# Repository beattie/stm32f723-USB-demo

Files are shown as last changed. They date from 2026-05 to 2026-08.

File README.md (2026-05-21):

# STM32F723 USB Passthrough Demo

A hardware and firmware demonstration platform based on the STM32F723VET6, a Cortex-M7
with an embedded USB HS PHY. Inspired by the [Pastilda](https://github.com/nickcoutsos/pastilda)
project, with a goal of providing robust Linux support for USB keyboard passthrough. This project was started as a vehicle to learn Rust and keep my USB up-to date as well as display my limited HW design abilities.

## Concept

The board sits between a USB keyboard and a Linux host. The firmware intercepts keystrokes,
allowing for key remapping, macros, and other HID transformations entirely in hardware —
no kernel modules or userspace daemons required on the host.

## Hardware

Designed in KiCad. The STM32F723 was chosen for its embedded USB HS PHY, which allows
full-speed USB HS without an external PHY chip.

**Key interfaces:**
- USB-C device port to host (USB 2.0 HS)
- USB-A host port for keyboard (USB FS)
- USB-C power input
- MicroSD — for config and macro storage
- SPI LCD connector — optional display
- SWD debug header

**Hardware versions:**
- Rev 0.1 — 2-layer board, initial bring-up (bring-up in progress)
- Rev 0.2 — 4-layer board (F.Cu / GND / 3V3 / B.Cu), revised layout (design in progress)

PCB gerbers for Rev 0.1 are in `kicad/gerbers/`.

## Firmware

Written in Rust using the [Embassy](https://embassy.dev/) async embedded framework.

```
src/main.rs      — application entry point
Cargo.toml       — dependencies
memory.x         — linker memory map for STM32F723VE
```

**Build:**
```bash
cargo build --release
```

Requires the `thumbv7em-none-eabihf` target:
```bash
rustup target add thumbv7em-none-eabihf
```

**Flash:**
```bash
cargo flash --release --chip STM32F723VETx
```
Or use OpenOCD/probe-rs via the SWD header.

## Bill of Materials

See [BOM.md](BOM.md) for the full parts list with Digikey part numbers.

## License

Hardware and firmware are released under CERN-OHL-S v2 / GPL v3 respectively.

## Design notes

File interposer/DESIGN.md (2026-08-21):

# Interposer Secure Storage Device — Design Draft

## Overview

A USB interposer device that sits between a keyboard and a host computer. It presents as a composite USB device: a HID keyboard (passthrough) and a mass storage device (SD card). The device provides two security services:

1. **Password manager** — stores credentials encrypted on SD; types them via HID on user request
2. **Secure file store** — stores encrypted files on SD; decrypts and transfers content to host via HID typing or a temporary plaintext staging file

The host requires no special software. All security operations are performed on the device using the passthrough keyboard for input and the ST7735 display for UI.

---

## Threat Model

**Protected against:**
- Theft of SD card alone — all sensitive content is encrypted
- Theft of device alone — requires user passphrase to derive key
- Brute force of passphrase — KDF is intentionally slow; device secret adds a second factor

**Not protected against:**
- Physical possession of device AND knowledge of passphrase
- Host keyloggers (HID typing path exposes plaintext to a compromised host)
- Destruction or corruption of SD card contents

**Out of scope:**
- Protection against a sophisticated attacker with lab equipment and the physical device
- Forward secrecy
- Multi-user access

---

## Hardware

- **SoC**: STM32F723VET6, Cortex-M7, 216MHz
- **Storage**: Full-size SD card via SDMMC1 (1-bit mode, 4-bit pending)
- **Display**: ST7735 1.44" 128×128 SPI
- **USB device**: OTG_HS (USB-C), composite HID keyboard + MSC
- **USB host**: OTG_FS (USB-A), HID keyboard input
- **TRNG**: STM32 hardware RNG — used for salt/nonce/key generation
- **Unique ID**: STM32 96-bit factory UID at 0x1FF0F420 — part of device secret

---

## Key Derivation

```
device_secret = flash_secret || uid_96bit
encryption_key = Argon2id(
    passphrase  = user_passphrase,
    salt        = device_secret,
    m = 65536,          // 64MB memory — adjust for RAM constraints
    t = 3,              // iterations
    p = 1               // parallelism
)
```

**flash_secret**: 32 bytes of TRNG-generated random data, written to a dedicated flash sector during first-boot provisioning. Never exposed over any interface. Protected by STM32 RDP Level 1 when device is sealed.

**uid_96bit**: Factory-programmed, read-only. Ensures encryption_key is device-specific even if flash_secret is somehow compromised.

**Note**: STM32F723 has 256KB RAM. Argon2id memory parameter must fit — 64MB does not. Realistic target is 128–256KB. This weakens brute-force resistance; compensate with a stronger passphrase.

---

## Flash Layout

```
Sector 0–N-1   Firmware
Sector N        Device secret (32 bytes TRNG, written once at provisioning)
                [ remainder of sector unused ]
```

Sector N chosen to avoid firmware overlap. At RDP Level 1, entire flash is unreadable externally. At RDP Level 2, device is permanently sealed.

---

## SD Card Layout

Ordinary FAT32 filesystem, mountable on any host. Sensitive files use the `.sec` extension — opaque encrypted blobs to any host without the key.

```
/
├── password.sec       — encrypted password database
├── README.txt         — plaintext, explains the device to a curious host user
└── files/
    └── *.sec          — user encrypted files
```

The host can freely copy, move, or delete `.sec` files. The device manages their contents.

---

## Encrypted Object Format

```
Offset  Size  Field
0       4     Magic: "ISEC"
4       1     Version: 0x01
5       1     Type: 0x01=password_db, 0x02=text_file, 0x03=binary_file
6       2     Reserved
8       12    Nonce (TRNG-generated per encryption)
20      4     Plaintext length
24      N     ChaCha20-Poly1305 ciphertext + 16-byte tag
```

**Cipher**: ChaCha20-Poly1305 (AEAD) — software implementation via RustCrypto, no hardware CRYP needed. Provides confidentiality + integrity; a tampered file will fail authentication.

---

## Password Database Format (plaintext, before encryption)

INI-style, section-per-entry. Human-readable and editable with any text editor before encryption.

```ini
IPMGR

[github.com]
username = beattie
password = Kx7!mP2#qL
comment = work account

[gmail.com]
username = beattie@gmail.com
password = correct-horse-battery
```

**Rules:**
- First line is the magic header `IPMGR`
- Each entry is a `[section]` where the section name is the site label shown on the display
- Fields are `key = value` — order within a section does not matter
- Blank lines between entries are ignored
- Unknown fields are preserved on re-write (forward compatibility)
- `comment` field is optional — shown on display, not typed to host

**Known fields:** `username`, `password`, `comment`

**Open question:** encrypt the whole file as one blob, or encrypt only the password fields and keep structure plaintext. Whole-file is simpler and leaks no metadata; per-field allows browsing entry names without the key. Decision deferred.

After encryption stored as `password.sec`.

---

## Device Modes / State Machine

```
LOCKED
  │  user types passphrase on keyboard
  ▼
UNLOCKED
  ├── PASSTHROUGH   — keystrokes forwarded to host normally
  ├── PM_SELECT     — display shows credential list; Up/Down selects
  ├── PM_TYPE_USER  — device types username via HID
  ├── PM_WAIT       — waiting for user to press Enter/Tab to type password
  └── FILE_SELECT   — display shows file list; select to decrypt+transfer
```

**Trigger**: a key combination (e.g. Scroll Lock, or a configurable combo) switches from PASSTHROUGH to PM_SELECT while unlocked.

**Lock**: device re-locks after configurable idle timeout, or on explicit lock key combo. Derived key is zeroed from RAM.

---

## Transfer Mechanisms

**Password typing (PM path):**
1. Device decrypts `password.sec` in RAM
2. User selects entry on display
3. On Enter: device types username via HID
4. On next Enter: device types password via HID
5. Plaintext held in RAM only; zeroed after use

**Secure file transfer:**
1. User selects `.sec` file on display
2. Device decrypts to RAM (size limited by available RAM — ~200KB usable)
3. Device creates `PLAIN.TXT` on FAT, writes plaintext
4. Host reads file normally (no special software)
5. After timeout (e.g. 60s) or explicit lock: device overwrites `PLAIN.TXT` with zeros, deletes it
6. Display shows countdown

**Encrypt a host-written file:**
1. Host writes plaintext file to FAT (e.g. `newfile.txt`)
2. User selects it on device display, confirms
3. Device reads plaintext, encrypts, writes `newfile.sec`, deletes `newfile.txt`

---

## Password Entry & Generation

### Manual entry

New credentials entered on-device using the passthrough keyboard:

1. User triggers "new entry" mode from PM_SELECT
2. Display shows `Site:` — user types site/username, presses Enter
3. Display shows `Password:` — user types password, OR presses a key to generate
4. Device appends entry to `password.sec` (decrypt → append → re-encrypt)

### Random generation

- **Source**: STM32 hardware TRNG — already present, used for nonces
- **Character set**: `a-z A-Z 0-9 !@#$%^&*-_+=` (no ambiguous chars like `0O1lI`)
- **Default length**: 20 characters; configurable 12–32
- **UX**: generated password shown on display before committing — user can confirm or regenerate
- **On confirm**: entry stored in `password.sec` AND typed to host via HID so the site receives it immediately

Word-based (diceware) passwords not implemented: wordlist (~80KB) would need to live on SD card, adds complexity, and many sites reject passphrases.

### Implementation dependency

Both manual entry and random generation require a **text input loop**: reading keystrokes from the passthrough keyboard (already captured in `kbd_task`) and echoing masked input on the display. This is the foundation all password manager UI builds on.

---

## Future Features

### FIDO2 / WebAuthn

A FIDO2 token eliminates the need to type passwords entirely for supported sites. The site sends a challenge, the device signs it with a per-site private key, the site verifies. The secret never leaves the device — immune to host keyloggers and phishing, stronger than HID typing for authentication.

**What's needed:**
- CTAP2 protocol over USB HID (usage page 0xF1D0) — a separate HID interface alongside the keyboard HID; embassy-usb supports multiple HID interfaces
- Per-site EC key pairs (P-256 or Ed25519), generated on device, stored encrypted on SD
- User presence confirmation — button press or PIN; display can show which site is requesting
- Resident keys (discoverable credentials) for passwordless login
- Spec: FIDO Alliance CTAP2 (open); reference implementation: SoloKeys (open source)

**Fit with this hardware:**
- Display is a genuine advantage over most FIDO2 tokens — can show the relying party ID before confirming
- RustCrypto has P-256 (`p256`) and Ed25519 (`ed25519-dalek`)
- Flash estimate: ~80KB additional

**Priority:** High — clean security model, open spec, good open source reference, doesn't require host software once registered.

---

### Monero Support

Monero's view key / spend key separation is well-suited to a hardware wallet: share the view key with a watch-only wallet to monitor incoming transactions, keep the spend key on the device.

**Realistic subset (feasible on this hardware):**
- Seed storage (Monero 25-word or BIP39 format) — encrypted on SD, same key derivation as secure storage
- View key export — derive and display/type the view key for import into Feather Wallet or Monero CLI
- Ed25519-Monero signing for simple transactions
- Host interface: Trezor protocol (Feather Wallet already supports it) or custom

**What's probably out of reach:**
- Full RingCT / Bulletproofs proving — computationally and memory intensive; Bulletproofs require significant RAM for the proof construction
- Full privacy-preserving transaction signing on-device

**What's needed:**
- Ed25519-Monero curve arithmetic (a variant of standard Ed25519) — RustCrypto `curve25519-dalek` is a starting point
- Monero key derivation (Keccak-256, not SHA-3) — RustCrypto `tiny-keccak`
- Companion software on host required (Feather Wallet or Monero CLI with hardware wallet support)
- Reference: Trezor Monero implementation (open source)

**Flash estimate:** ~100KB for Ed25519-Monero + key derivation + Trezor protocol subset.

**Priority:** Medium — personally useful (eris Monero node), simpler subset is feasible, full RingCT is not.

---

### Code Space Reality Check (STM32F723: 512KB flash, 256KB RAM)

| Component | Flash estimate |
|---|---|
| Current firmware (USB host+device, MSC, display, SD) | ~150KB |
| Secure storage (ChaCha20-Poly1305, Argon2id, FAT) | ~100KB |
| FIDO2 (CTAP2, P-256/Ed25519, key storage) | ~80KB |
| Monero subset (Ed25519-Monero, seed, view key) | ~100KB |
| **All four** | **~430KB** — tight but possibly feasible |

RAM is the harder constraint. Argon2id memory parameter and crypto buffers compete with USB stack and task stacks. Measure actual usage after core secure storage is implemented before committing to FIDO2 + Monero simultaneously.

---

## Open Questions

1. **Argon2id memory parameter** — 256KB RAM leaves very little headroom after firmware stack/data. May need PBKDF2 instead, with a stronger passphrase requirement.
2. **Key caching** — re-derive key on each operation, or cache in RAM for the session? Caching is faster but key lives in RAM longer.
3. **Passphrase entry UX** — display shows character count only (no echo), or masked echo (dots)? Confirmation by retyping?
4. **File size limit** — decrypt-to-RAM limits secure files to ~150–200KB. Larger files need streaming decrypt, which is more complex.
5. **Staging file timing** — fixed timeout for `PLAIN.TXT` exposure, or user-initiated wipe?
6. **Provisioning UX** — first boot generates and writes flash_secret automatically, or requires an explicit provisioning step?
7. **RDP sealing** — manual step, or triggered from device UI?

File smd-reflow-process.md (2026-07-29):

# SMD Reflow Process — Electric Skillet

## Equipment and Materials

- Electric skillet (dedicated, not for food)
- IR thermometer with adjustable emissivity (Surpeer GM550)
- Laser-cut stencil (0.12mm for mixed 0603 / LQFP100 0.5mm pitch)
- Solder paste: Chip Quik TS391AX50 Sn63Pb37 no-clean
- Scrap PCB (temperature reference target — see Skillet Setup)
- Squeegee or old credit card
- Tweezers (fine tip) or vacuum pen for component placement
- Isopropyl alcohol 90%+ and toothbrush for cleaning
- Silicone soldering mat (table protection)
- Magnification (loupe or microscope) for inspection
- Solder wick and flux for rework

---

## Paste Storage

- Store paste refrigerated when not in use
- Before use: remove from fridge, leave **closed** at room temperature for 30–60 minutes
- Opening a cold jar causes condensation which contaminates the paste
- Once opened, paste has a working life of several hours; do not leave uncovered
- Return unused paste to the fridge

NB: Chip Quick TS391AX50 is listed as Thermally Stable, may not need redrigeration.

---

## Skillet Setup

1. Place silicone mat on work surface, skillet on top
2. **Do not use aluminum foil** — foil acts as a heat sink and limits peak temperature to ~190°C, which is below the reflow zone for Sn63Pb37. Without foil, the skillet surface cycles correctly between 200–220°C.
3. Place a scrap PCB in the skillet as your IR temperature reference target. Set IR thermometer emissivity to ε=0.95 and read the bare PCB surface — permanent marker on PCB reads essentially the same as bare PCB, either works. Keep the reference PCB close to where your board will sit.

**What does not work for IR reference:**
- Bare skillet surface: reads 30–50°C cold (reflective metal)
- Black electrical tape on skillet: also reads cold, and puckers/deforms above 150°C (PVC melts)
- Black tape or marker must be on a PCB substrate to give accurate readings

---

## Skillet Calibration (First Use)

Map your dial to actual temperature before reflowing a real board:

1. Place scrap PCB reference in skillet; set IR thermometer to ε=0.95
2. Turn skillet to maximum (no foil)
3. Measure PCB temperature at intervals and note the time

**Observed ramp (this skillet, cold start ~28–33°C, maximum dial, no foil):**

| Time | PCB Temperature | Event |
|---|---|---|
| 0:00 | 28–33°C | Start |
| 4:00 | ~150°C | |
| 6:12 | 183°C | Liquidus (up) |
| 6:21 | ~191°C | Paste goes shiny |
| 7:00 | ~200°C | |
| 8:30 | ~220°C | |

Ramp rate is ~0.4°C/s — slow enough that the paste preheat/soak profile is satisfied naturally on the way up. No need to hold at an intermediate temperature. **Liquidus onset is consistent at ~6:21 across multiple runs.**

**Time above liquidus (TAL) by kill-heat strategy:**

| Strategy | Kill heat | TAL | Peak | Suitable for components? |
|---|---|-----|---|---|
| 220°C dial mark / neon out | ~8:01 | ~5 min | 222°C | No — 6× over spec |
| Max dial / neon out | ~10:17 | ~9 min | 249°C | No — way over spec |
| **Liquidus + 30–60s** | **~6:50–7:20** | **~90–108s** | **~200–205°C** | **Yes ✓** |

**Use the liquidus + 30–60s strategy for all populated boards.** The neon-out strategies give excessive TAL and excessive peak temperatures regardless of dial setting — the neon is useful only as a calibration reference, not as the reflow trigger.

**Cooldown:** Move board to silicone mat once reference PCB reads 150°C (solder solidified well above this — tap a large pad gently to confirm if unsure).

Skillet dials are inaccurate — calibrate before first use and mark the dial.

---

## Stencil and Paste Application

### Alignment
1. Secure the bare PCB flat on your work surface — tape the corners or use a frame to prevent movement
2. Lay the stencil over the board, aligning apertures to pads
3. Hold or tape the stencil edges so it cannot shift during squeegee pass
4. The stencil must lie flat with no gap between stencil and board surface — paste will bleed under a lifted stencil

### Paste Application
1. Apply a bead of paste along one edge of the stencil (slightly more than you think you need)
2. Hold squeegee or credit card at **45°** angle
3. Draw across the stencil in **one firm, smooth pass** — don't go back and forth
4. Consistent pressure and angle give consistent paste volume
5. Carefully lift the stencil **straight up** — peeling at an angle smears the deposits

### Inspection Before Placing Parts
- Check every pad under magnification before placing components
- Look for: missed pads, bridges between adjacent pads, uneven deposit volume
- Fine-pitch pads (LQFP100) are most likely to bridge — inspect carefully
- Fix problems now with a toothpick; much harder after components are placed

---

## Component Placement

- Work from smallest/lowest components to largest/tallest
- Tweezers: fine tip, grip component by the body not the leads
- Vacuum pen: faster for larger components, less control on small ones
- Place components into the paste — they should sit level and centered on the pads
- Paste is tacky enough to hold parts in place; don't press hard or you'll displace paste
- Double-check orientation on polarized components (caps, diodes, ICs) before reflow — much easier to fix now

---

## Reflow

### Temperature Profile (Sn63Pb37)
| Phase | Temperature | Notes |
|---|---|---|
| Preheat | ramp to ~150°C | Activates flux, evaporates solvents |
| Soak | hold ~150°C briefly | Equalizes board temperature |
| Reflow | push to 205–215°C | Watch for paste transition |
| Cool | kill heat, leave on skillet | Let solder solidify before moving |

### Process
1. Place scrap PCB reference target in skillet next to where the board will sit
2. Place populated board on **cold** skillet
3. Turn dial to **maximum**
4. Wait — expect approximately **8–9 minutes** before reflow at this ramp rate. The slow ramp naturally covers the preheat and soak phases on the way up; no intermediate dial step needed.
5. Watch the paste: it will go dull/gray → slightly transparent (flux working) → **bright shiny silver** (reflow). The visual transition is the primary trigger — timing is only a rough guide. **Tip:** apply a small dab of paste to a visible test point or exposed pad — gives an unobstructed view of the reflow transition since paste under IC pins can't be seen directly.
6. Once reflow is visible, start a timer and hold for **30–60 seconds**
7. **Kill the heat** — turn dial to off. Do not wait for the neon pilot light to go out; that gives ~5–9 minutes TAL depending on dial setting, which is too long for components.
8. Leave board on skillet. Move to silicone mat once reference PCB reads **150°C** — solder is solid well before this point. Tap a large pad gently to confirm solidity if uncertain.

---

## Post-Reflow Inspection

Under magnification, check for:

- **Good joint**: shiny, smooth fillet, wets both pad and component lead
- **Bridge**: solder connecting two adjacent pads — most common on fine-pitch
- **Tombstone**: component standing on one end, one pad reflowed before the other — caused by uneven paste or component not centered
- **Cold joint**: dull, grainy surface — insufficient temperature or movement during solidification
- **Insufficient solder**: pad wetted but joint looks thin — check paste volume on stencil setup

---

## Rework

### Bridges
1. Apply liquid flux to the bridge
2. Touch solder wick to the bridge with a hot iron — wick pulls excess solder away
3. Clean flux residue with IPA

### Tombstoned Component
1. Apply flux
2. Reflow both pads with hot air or iron, press component flat while liquid
3. Alternatively: remove component, clean pads, re-paste, replace

### Cold Joint
1. Apply flux
2. Reflow with iron or hot air — good flux and heat usually fixes it

### Hand Application (Single Pads / Rework Only)
- Use a toothpick or syringe to apply a small amount of paste to individual pads
- Or use flux + solder wire with an iron for single joints
- Not recommended for whole-board paste application

---

## Cleaning

Chip Quik TS391AX50 is no-clean — residue is non-corrosive and can be left on the board. Cleaning is still recommended:

1. Apply IPA (90%+) to board
2. Scrub with toothbrush, working around components
3. Rinse with fresh IPA
4. Allow to dry completely before powering up

---

## Ventilation

Flux fumes during reflow are unpleasant and mildly irritating. Work near an open window or with a fan exhausting away from you. A small fume extractor is worthwhile if you do this regularly.

---

## Notes

- **Do not mix bismuth and tin-lead solder** — the alloys blend and the melting point drops unpredictably
- Bismuth paste (lower temp ~138°C) is useful for learning skillet technique but produces more brittle joints
- Tin-lead (Sn63/Pb37) is preferred for production boards — sharper melt at 183°C, more forgiving
- Stencil thickness: **0.12mm** for mixed 0603 / LQFP100 0.5mm pitch

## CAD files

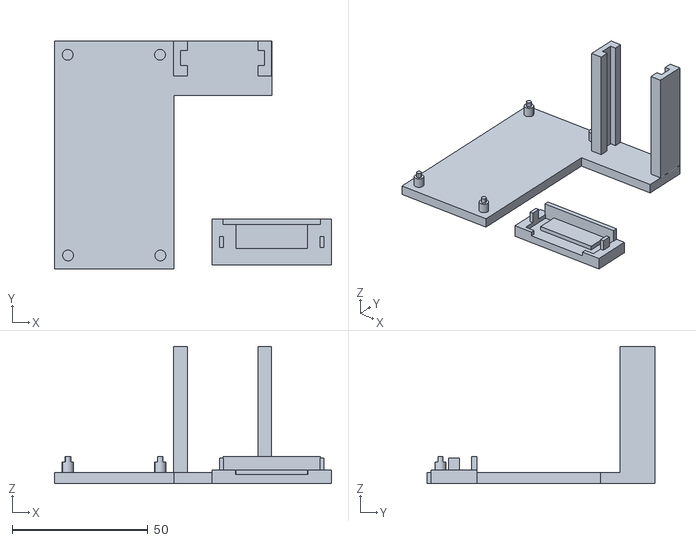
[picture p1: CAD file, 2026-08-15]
3dprint/baseplate_display.stl
102.0 x 84.0 x 50.5

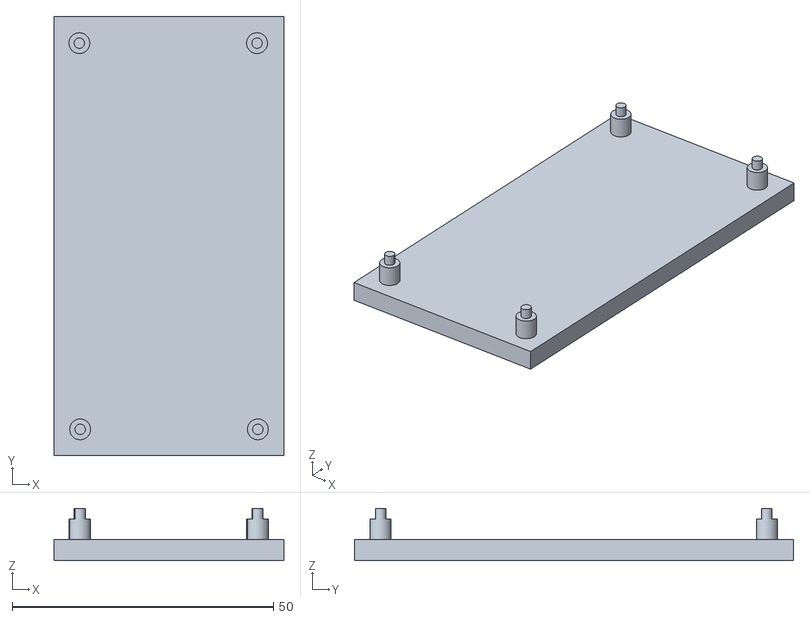
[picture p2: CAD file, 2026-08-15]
3dprint/baseplate.stl
44.0 x 84.0 x 10.0

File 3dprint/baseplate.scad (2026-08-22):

// STM32F723 USB Interposer board base plate
// This is a Q&D hack to solve two problems,
// since there is a connector on the bottom
// the board tends to rock when probeing, the
// display just tends to flop around and not
// be visable. This fixes both, it is not
// well fitted or elegant.
//
// Board: 40x80mm, 4x M2.2 mounting holes
// Standoffs: 4mm dia, 4mm tall; pins: 2mm dia,
// 2mm tall (for 2mm screws / press fit)

board_w      = 40;
board_h      = 80;
margin       = 2;       // extra plate beyond board edge on each side
plate_thick  = 4;
standoff_d   = 4;
standoff_h   = 4;
pin_d        = 2;       // fits 2.2mm hole with 0.1mm clearance each side
pin_h        = 2;

display_w    = 30;
display_h    = 43.5;
display_t    = 5;
extension_w  = 36;
extension_l  = 20;

plate_w = board_w + 2*margin;
plate_l = board_h + 2*margin;

// Hole positions relative to board top-left corner (mm), from KiCad PCB
holes = [
    [ 3.00,  3.00 ],   // top-left
    [37.00,  3.00 ],   // top-right
    [ 2.85, 76.90 ],   // bottom-left
    [36.85, 76.90 ],   // bottom-right
];

mounting_pins = false;	// true pins on top of standoffs or screw holes

module standoff(x, y) {
    translate([margin + x, margin + y, plate_thick]) {
		if (mounting_pins) {
			union() {
        		cylinder(h=standoff_h, d=standoff_d, $fn=36);
        		translate([0, 0, standoff_h])
            		cylinder(h=pin_h, d=pin_d, $fn=36);
			}
		} else {
			difference() {
        		cylinder(h=standoff_h, d=standoff_d, $fn=36);
        		translate([0, 0, 0])
            		cylinder(h=pin_h + standoff_h, d=pin_d, $fn=36);
			}
		}
    }
}

module keeper()
{
	difference() {
		cube([extension_w + 8, display_t + 8 + 4, 5], center=true);
		translate([extension_l - 4.5, 0, -2])
			cube([4.5, display_t + 8.5, 2.5], center = true);
		translate([-extension_l + 4.5, 0, -2])
			cube([4.5, display_t + 8.5, 2.5], center = true);
		translate([0, display_t + 1.5, -2])
			cube([display_w - 3.25, 8, 2.5], center = true);
	}
	translate([0, -display_t - 2.5, -4])
		cube([extension_w, 2, 3], center=true);
	translate([extension_l - 1.5, 0, -4])
		cube([1.5, 4, 6], center = true);
	translate([-extension_l + 1.5, 0, -4])
		cube([1.5, 4, 6], center = true);
}

module base_plate()
{
	// Base plate
	cube([plate_w, plate_l, plate_thick]);

	// Standoffs at each mounting hole
	for (h = holes)
    	standoff(h[0], h[1]);
}

module display()
{
	// Display extension
	translate([plate_w - 0.1, plate_l - extension_l, 0]) {
		cube([extension_w + 0.1, extension_l, plate_thick]);
		translate([0, 0, -5]) rotate([15, 0, 0]) {
			translate([0, 0, plate_thick]) difference() {
				union() {
					translate([0, extension_l - display_t - 8, 0])
							cube([5, display_t + 8, display_h + 3]);
					translate([extension_w - 5,
							extension_l - display_t - 8, 0])
						cube([5, display_t + 8, display_h + 3]);
				}
				translate([2.75, extension_l - 9, 0])
					cube([display_w+0.5, display_t + 0.5, display_h+5]);
			}
		}
	}
}

base_plate();
display();
translate([board_w * 2, display_t*2, 2.5]) rotate([180, 0, 0]) keeper();

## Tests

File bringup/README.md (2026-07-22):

Note: Drivers/CMSIS and Drivers/STM32F7xx_HAL_Driver are not committed (152MB).
Regenerate via STM32CubeMX using STM32F723_bringup.ioc, or copy from a CubeMX installation.

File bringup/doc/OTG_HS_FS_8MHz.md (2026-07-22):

# OTG_HS Full-Speed Mode with 8 MHz Crystal

Yes, you can absolutely configure the OTG_HS peripheral to operate strictly in
Full-Speed (FS) mode using your 8 MHz crystal.

This is a highly effective hardware strategy for your v0.1 bring-up. By forcing
the OTG_HS controller into Full-Speed mode (12 Mbps), you completely bypass the
integrated High-Speed PHY and its strict 12/16/24 MHz crystal requirements.
Instead, the controller shifts its tracking and logic to use standard, stable
48 MHz clock routing supplied by your Main PLL, which can easily be generated
from your 8 MHz hardware.

Here is how to configure it to successfully pass CubeMX validation and run on
your board:

## 1. Fix the CubeMX Clocks First (The 12 MHz Bypass)

Because CubeMX enforces strict software checks, it will automatically throw a
clock configuration error if you select the OTG_HS peripheral while the input
frequency box says 8 MHz.

In the **Clock Configuration** tab, set the **Input Frequency (HSE value)** to
**12 MHz** just to clear the user interface restriction.

Set your Main PLL parameters explicitly to handle your actual physical 8 MHz
crystal:

| Parameter | Value |
|---|---|
| M | 8 |
| N | 384 |
| Q | 8 |

Q=8 yields exactly 48 MHz on your real board, satisfying the target FS USB core
clock requirements.

## 2. Configure the OTG_HS Peripheral in Full-Speed Mode

1. Go to **Pinout & Configuration** → **Connectivity** → **USB_OTG_HS**.
2. Set the **Mode** dropdown to **Device_Only** or **Host_Only** depending on
   your design.
3. In the **Parameter Settings** block, locate the **Speed** parameter and
   change it from *High Speed* to **Full Speed 12 MBit/s**.
4. Ensure **Physical Interface (PHY)** is set to **Internal FS PHY**. Do not
   select "Internal HS PHY" — that triggers the broken 8 MHz initialization
   logic loop inside the transceiver.

## 3. Verify Physical Pins

When you configure OTG_HS in internal Full-Speed mode, the USB differential
pair routes through:

- **PB14** — USB_OTG_HS_DM
- **PB15** — USB_OTG_HS_DP

Make sure your USB-C connector is wired to PB14/PB15, not PA11/PA12 (which are
reserved for the standalone OTG_FS block).

Once you generate code under this configuration, the ST HAL drivers
(`stm32f7xx_hal_pcd.c`) will initialize the engine using `USB_OTG_SPEED_FULL`,
letting your host enumerate the board at 12 Mbps using your 8 MHz crystal.

## Caveats

The "set HSE to 12 MHz in CubeMX to bypass the check" trick is a hack — the
generated `SystemClock_Config` will have the wrong PLLM value for your actual
8 MHz crystal. Hand-correct it after code generation (or set HSE to 8 MHz and
fix CubeMX's complaints manually).

Also note: bypassing VBUS detection (GCCFG VBDEN=0) may be required on v0.1
where PB13 is NC, to prevent BSVLD=0 from blocking the D+ pull-up even when
using the internal FS PHY path (PHYSEL=1).

---

# Configuring OTG_HS as a USB HID Keyboard

To configure the OTG_HS interface (acting in Full-Speed mode on pins PB14/PB15)
as a USB HID Keyboard, set up the middleware parameters in STM32CubeMX. Once
generated, you only need to modify a small buffer array payload in your code to
start sending keystrokes to your computer.

## 1. CubeMX Middleware Configuration

1. Go to the **Pinout & Configuration** tab.
2. In the left sidebar, expand **Middleware and Software Packs** and click
   **USB_DEVICE**.
3. Change the **Class For HS IP** dropdown to
   **Human Interface Device Class (HID)**.
4. In the **Parameter Settings** tab below, ensure **HID Boot Protocol** is set
   to **Keyboard**.

> **Note:** CubeMX names the parameter "Class For HS IP" because you are
> technically using the High-Speed peripheral block, even though it is forced to
> operate at Full-Speed.

## 2. Verify Generated Descriptor

Generate your code and open the project. The ST HAL automatically configures the
correct USB HID descriptors for a keyboard based on your selection. Verify this
in the generated file:

- **File:** `USB_DEVICE/App/usbd_hid_if.c`
- Look for `HID_MOUSE_ReportDesc` — ST uses the "Mouse" naming convention in
  some older template strings, but the internal arrays are mapped for keyboards
  when toggled in CubeMX. You will see the standard 63-byte HID keyboard report
  descriptor.

## 3. Writing the Keystroke Code

A standard USB HID Keyboard report requires an 8-byte buffer:

| Byte | Description |
|---|---|
| 0 | Modifier keys (Ctrl, Shift, Alt, GUI/Windows) |
| 1 | Reserved — always `0x00` |
| 2–7 | Up to 6 simultaneous key codes (e.g. `0x04` = 'A') |

To send a keystroke, send the key-press report immediately followed by an empty
report to simulate key release.

Add this helper function to `main.c` inside the `/* USER CODE BEGIN 4 */` block:

```c
#include "usbd_hid.h"
extern USBD_HandleTypeDef hUsbDeviceHS;

void USB_Send_Key(uint8_t modifier, uint8_t keycode)
{
    uint8_t report_buffer[8] = {0};

    /* Key press */
    report_buffer[0] = modifier;
    report_buffer[2] = keycode;
    USBD_HID_SendReport(&hUsbDeviceHS, report_buffer, 8);
    HAL_Delay(20);

    /* Key release — crucial to prevent stuck keys */
    report_buffer[0] = 0;
    report_buffer[2] = 0;
    USBD_HID_SendReport(&hUsbDeviceHS, report_buffer, 8);
    HAL_Delay(20);
}
```

## 4. Test Loop in Main

Inside the `while(1)` loop in `main.c`, add a test routine that presses a
character every 5 seconds:

```c
/* USER CODE BEGIN WHILE */
while (1)
{
    /* Sends lowercase 'a' (HID code 0x04) */
    USB_Send_Key(0, 0x04);

    /* Sends uppercase 'A' by holding Left Shift (modifier 0x02) */
    /* USB_Send_Key(0x02, 0x04); */

    HAL_Delay(5000);
    /* USER CODE END WHILE */

    /* USER CODE BEGIN 3 */
}
/* USER CODE END 3 */
```

## HID Key Code Reference

| Key | Code |
|-----|---|
| 'A'–'Z' | `0x04`–`0x1D` |
| '1'–'0' | `0x1E`–`0x27` |
| Return/Enter | `0x28` |
| Left Shift (modifier) | `0x02` |
| Left Ctrl (modifier) | `0x01` |

When you plug the v0.1 board into a USB port via PB14/PB15, it will enumerate
as a hardware keyboard and type characters directly into the active text editor.

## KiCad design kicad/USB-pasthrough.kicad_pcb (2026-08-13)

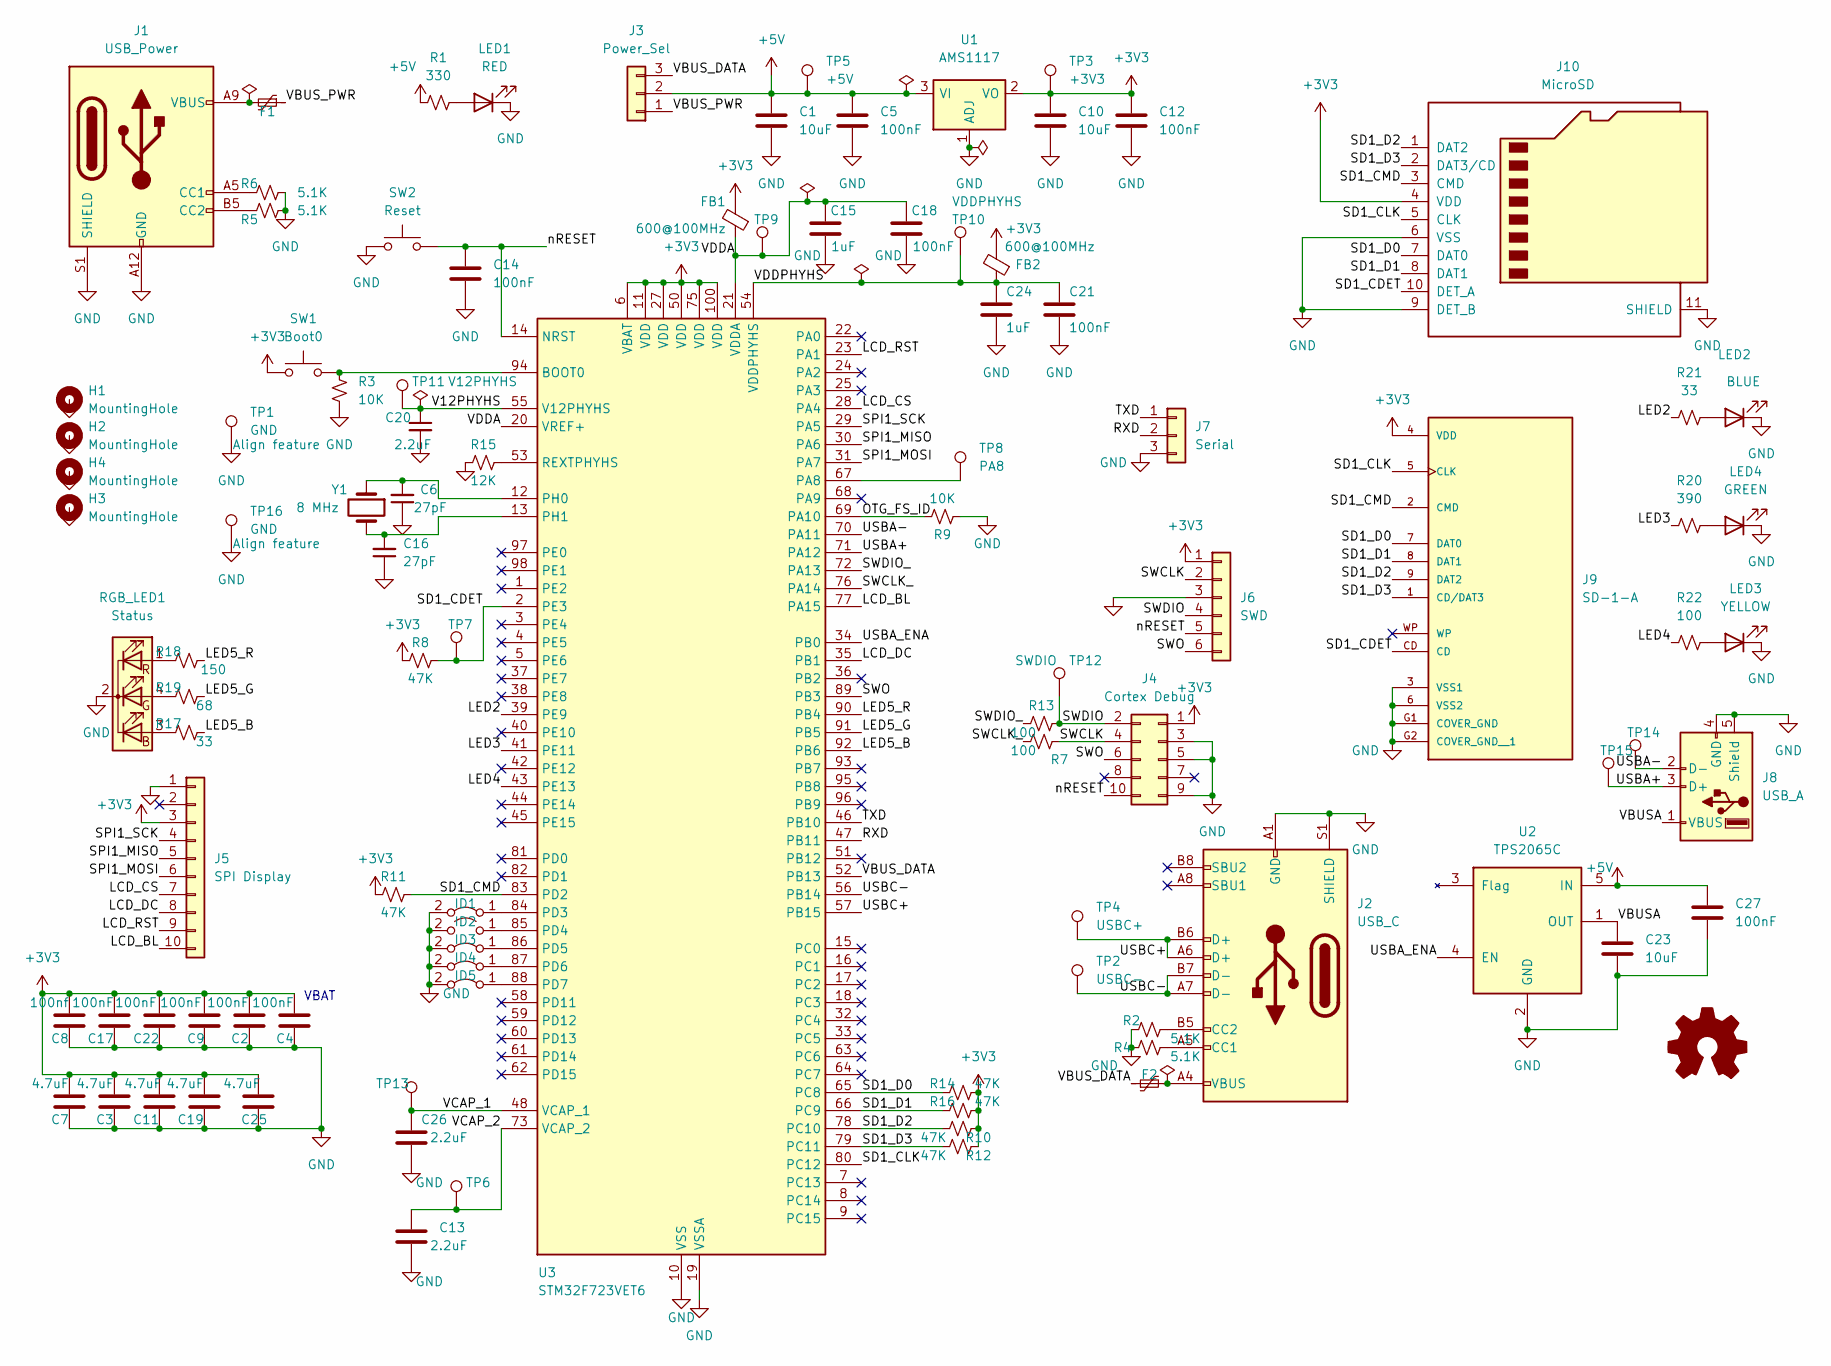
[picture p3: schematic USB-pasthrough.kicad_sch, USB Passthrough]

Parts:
C1, C10: 10uF; CP_Radial_D5.0mm_P2.50mm
C2, C4, C5, C9, C12, C14, C17, C18, C21, C22, C27: 100nF; C_0603_1608Metric_Pad1.08x0.95mm_HandSolder
C3, C7, C11, C19, C25: 4.7uF; C_0603_1608Metric_Pad1.08x0.95mm_HandSolder
C6, C16: 27pF; C_0603_1608Metric_Pad1.08x0.95mm_HandSolder
C8: 100nf; C_0603_1608Metric_Pad1.08x0.95mm_HandSolder
C13, C20, C26: 2.2uF; C_0603_1608Metric_Pad1.08x0.95mm_HandSolder
C15, C24: 1uF; C_0603_1608Metric_Pad1.08x0.95mm_HandSolder
C23: 10uF; C_0603_1608Metric_Pad1.08x0.95mm_HandSolder
F1, F2: F; Fuse_1812_4532Metric_Pad1.30x3.40mm_HandSolder
FB1, FB2: 600@100MHz; L_0603_1608Metric_Pad1.05x0.95mm_HandSolder
H1, H2, H3, H4: MountingHole; MountingHole_2.2mm_M2_Pad
ID1, ID3, ID4, ID5: Jumper_2_Bridged; SolderJumper-2_P1.3mm_Bridged_Pad1.0x1.5mm
ID2: Jumper_2_Bridged; SolderJumper-2_P1.3mm_Open_Pad1.0x1.5mm
J1: USB_Power; USB_C_Receptacle_GCT_USB4135-GF-A_6P_TopMnt_Horizontal
J2: USB_C; USB_C_Receptacle_GCT_USB4085
J3: Power_Sel; PinHeader_1x03_P2.54mm_Vertical
J4: Cortex Debug; SAMTEC_SHF-105-01-F-D-TH
J5: SPI Display; PinHeader_1x10_P2.54mm_Vertical
J6: SWD; PinHeader_1x06_P2.54mm_Vertical
J7: Serial; PinHeader_1x03_P2.54mm_Vertical
J8: USB_A; USB_A_Molex_67643_Horizontal
J9: SD-1-A; CUI_SD-1-A; PARTREV 1.0
J10: MicroSD; microSD_HC_Hirose_DM3AT-SF-PEJM5
LED1: RED; LED_0603_1608Metric_Pad1.05x0.95mm_HandSolder
LED2: BLUE; LED_0603_1608Metric_Pad1.05x0.95mm_HandSolder
LED3: YELLOW; LED_0603_1608Metric_Pad1.05x0.95mm_HandSolder
LED4: GREEN; LED_0603_1608Metric_Pad1.05x0.95mm_HandSolder
R1: 330; R_0603_1608Metric_Pad0.98x0.95mm_HandSolder
R2, R4, R5, R6: 5.1K; R_0603_1608Metric_Pad0.98x0.95mm_HandSolder
R3, R9: 10K; R_0603_1608Metric_Pad0.98x0.95mm_HandSolder
R7, R13, R22: 100; R_0603_1608Metric_Pad0.98x0.95mm_HandSolder
R8, R10, R11, R12, R14, R16: 47K; R_0603_1608Metric_Pad0.98x0.95mm_HandSolder
R15: 12K; R_0603_1608Metric_Pad0.98x0.95mm_HandSolder
R17, R21: 33; R_0603_1608Metric_Pad0.98x0.95mm_HandSolder
R18: 150; R_0603_1608Metric_Pad0.98x0.95mm_HandSolder
R19: 68; R_0603_1608Metric_Pad0.98x0.95mm_HandSolder
R20: 390; R_0603_1608Metric_Pad0.98x0.95mm_HandSolder
RGB_LED1: Status; LED_D5.0mm-4_RGB
SW1: Boot0; SW_Push_6mm_2pin_5.08mm
SW2: Reset; SW_Push_6mm_2pin_5.08mm
TP1, TP16: GND; TestPoint_THTPad_D2.0mm_Drill0.8mm_Align
TP2: USBC-; TestPoint_Pad_D1.0mm
TP3: +3V3; TestPoint_Pad_D1.0mm
TP4: USBC+; TestPoint_Pad_D1.0mm
TP5: +5V; TestPoint_Pad_D1.0mm
TP6: VCAP_2; TestPoint_Pad_D1.0mm
TP7: SD1_CDET; TestPoint_Pad_D1.0mm
TP8: PA8; TestPoint_Pad_D1.0mm
TP9: VDDA; TestPoint_Pad_D1.0mm
TP10: VDDPHYHS; TestPoint_Pad_D1.0mm
TP11: V12PHYHS; TestPoint_Pad_D1.0mm
TP12: SWDIO; TestPoint_Pad_D1.0mm
TP13: VCAP_1; TestPoint_Pad_D1.0mm
TP14: USBA-; TestPoint_Pad_D1.0mm
TP15: USBA+; TestPoint_Pad_D1.0mm
U1: AMS1117; SOT-223-3_TabPin2
U2: TPS2065C; SOT-23-5
U3: STM32F723VET6; LQFP-100_14x14mm_P0.5mm
Y1: 8 MHz; Crystal_HC49-U_Vertical

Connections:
+3V3: C2.2, C3.2, C4.2, C7.2, C8.2, C9.1, C10.1, C11.1, C12.1, C17.2, C19.2, C22.1, C25.1, FB1.2, FB2.2, J4.1, J5.3, J6.1, J9.4 (VDD), J10.4 (VDD), R8.1, R10.1, R11.1, R12.1, R14.2, R16.2, SW1.2, TP3.1, U1.2 (VO), U3.6 (VBAT), U3.11 (VDD), U3.27 (VDD), U3.50 (VDD), U3.75 (VDD), U3.100 (VDD)
+5V: C1.1, C5.2, C27.1, J3.2, R1.1, TP5.1, U1.3 (VI), U2.5 (IN)
/LCD_BL: J5.10, U3.77 (PA15)
/LCD_CS: J5.7, U3.28 (PA4)
/LCD_DC: J5.8, U3.35 (PB1)
/LCD_RST: J5.9, U3.23 (PA1)
/LED2: R21.1, U3.39 (PE9)
/LED3: R20.1, U3.41 (PE11)
/LED4: R22.1, U3.43 (PE13)
/LED5_B: R17.2, U3.92 (PB6)
/LED5_G: R19.2, U3.91 (PB5)
/LED5_R: R18.1, U3.90 (PB4)
/OTG_FS_ID: R9.2, U3.69 (PA10)
/RXD: J7.2, U3.25 (PA3), U3.47 (PB11)
/SD1_CDET: J9.CD, J10.10 (DET_A), R8.2, TP7.1, U3.2 (PE3)
/SD1_CLK: J9.5 (CLK), J10.5 (CLK), U3.80 (PC12)
/SD1_CMD: J9.2 (CMD), J10.3 (CMD), R11.2, U3.83 (PD2)
/SD1_D0: J9.7 (DAT0), J10.7 (DAT0), R14.1, U3.65 (PC8)
/SD1_D1: J9.8 (DAT1), J10.8 (DAT1), R16.1, U3.66 (PC9)
/SD1_D2: J9.9 (DAT2), J10.1 (DAT2), R10.2, U3.78 (PC10)
/SD1_D3: J9.1 (CD/DAT3), J10.2 (DAT3/CD), R12.2, U3.79 (PC11)
/SPI1_MISO: J5.5, U3.30 (PA6)
/SPI1_MOSI: J5.6, U3.31 (PA7)
/SPI1_SCK: J5.4, U3.29 (PA5)
/SWCLK: J4.4, J6.2, R7.2
/SWCLK_: R7.1, U3.76 (PA14)
/SWDIO: J4.2, J6.4, R13.2, TP12.1
/SWDIO_: R13.1, U3.72 (PA13)
/SWO: J4.6, J6.6, U3.89 (PB3)
/TXD: J7.1, U3.24 (PA2), U3.46 (PB10)
/USBA+: J8.3 (D+), TP15.1, U3.71 (PA12)
/USBA-: J8.2 (D-), TP14.1, U3.70 (PA11)
/USBA_ENA: U2.4 (EN), U3.34 (PB0)
/USBC+: J2.A6 (D+), J2.B6 (D+), TP4.1, U3.57 (PB15)
/USBC-: J2.A7 (D-), J2.B7 (D-), TP2.1, U3.56 (PB14)
/V12PHYHS: C20.1, TP11.1, U3.55 (V12PHYHS)
/VBUSA: C23.1, J8.1 (VBUS), U2.1 (OUT)
/VBUS_DATA: F2.1, J3.3, U3.52 (PB13)
/VBUS_PWR: F1.1, J3.1
/VCAP_1: C26.1, TP13.1, U3.48 (VCAP_1)
/VCAP_2: C13.1, TP6.1, U3.73 (VCAP_2)
/VDDA: C15.1, C18.1, FB1.1, TP9.1, U3.20 (VREF+), U3.21 (VDDA)
/VDDPHYHS: C21.1, C24.1, FB2.1, TP10.1, U3.54 (VDDPHYHS)
/nRESET: C14.1, J4.10, J6.5, SW2.1, U3.14 (NRST)
GND: C1.2, C2.1, C3.1, C4.1, C5.1, C6.1, C7.1, C8.1, C9.2, C10.2, C11.2, C12.2, C13.2, C14.2, C15.2, C16.1, C17.1, C18.2, C19.1, C20.2, C21.2, C22.2, C23.2, C24.2, C25.2, C26.2, C27.2, ID1.2 (B), ID2.2 (B), ID3.2 (B), ID4.2 (B), ID5.2 (B), J1.A12 (GND), J1.B12 (GND), J1.S1 (SHIELD), J2.A1 (GND), J2.A12 (GND), J2.B1 (GND), J2.B12 (GND), J2.S1 (SHIELD), J4.3, J4.5, J4.9, J5.1, J6.3, J7.3, J8.4 (GND), J8.5 (Shield), J9.3 (VSS1), J9.6 (VSS2), J9.G1 (COVER_GND), J9.G2 (COVER_GND__1), J10.6 (VSS), J10.9 (DET_B), J10.11 (SHIELD), LED1.1 (K), LED2.1 (K), LED3.1 (K), LED4.1 (K), R2.2, R3.2, R4.2, R5.2, R6.2, R9.1, R15.2, RGB_LED1.2 (K), SW2.2, TP1.1, TP16.1, U1.1 (ADJ), U2.2 (GND), U3.10 (VSS), U3.19 (VSSA), U3.26 (VSS), U3.49 (VSS), U3.74 (VSS), U3.99 (VSS)
unnamed: C6.2, U3.12 (PH0), Y1.1
unnamed: C16.2, U3.13 (PH1), Y1.2
unnamed: F1.2, J1.A9 (VBUS), J1.B9 (VBUS)
unnamed: F2.2, J2.A4 (VBUS), J2.A9 (VBUS), J2.B4 (VBUS), J2.B9 (VBUS)
unnamed: ID1.1 (A), U3.84 (PD3)
unnamed: ID2.1 (A), U3.85 (PD4)
unnamed: ID3.1 (A), U3.86 (PD5)
unnamed: ID4.1 (A), U3.87 (PD6)
unnamed: ID5.1 (A), U3.88 (PD7)
unnamed: J1.A5 (CC1), R6.1
unnamed: J1.B5 (CC2), R5.1
unnamed: J2.A5 (CC1), R4.1
unnamed: J2.B5 (CC2), R2.1
unnamed: LED1.2 (A), R1.2
unnamed: LED2.2 (A), R21.2
unnamed: LED4.2 (A), R20.2
unnamed: LED3.2 (A), R22.2
unnamed: R3.1, SW1.1, U3.94 (BOOT0)
unnamed: R15.1, U3.53 (REXTPHYHS)
unnamed: R17.1, RGB_LED1.3 (BA)
unnamed: R18.2, RGB_LED1.1 (RA)
unnamed: R19.1, RGB_LED1.4 (GA)
unnamed: TP8.1, U3.67 (PA8)

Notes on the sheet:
VBAT

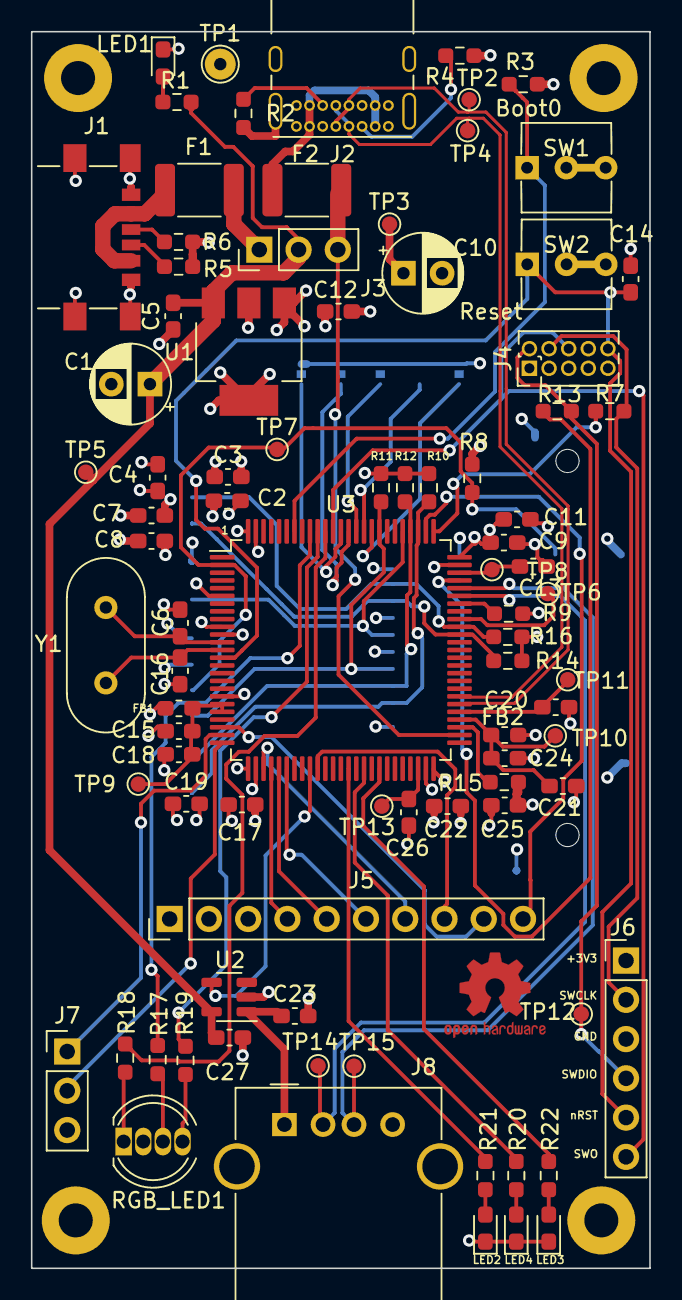
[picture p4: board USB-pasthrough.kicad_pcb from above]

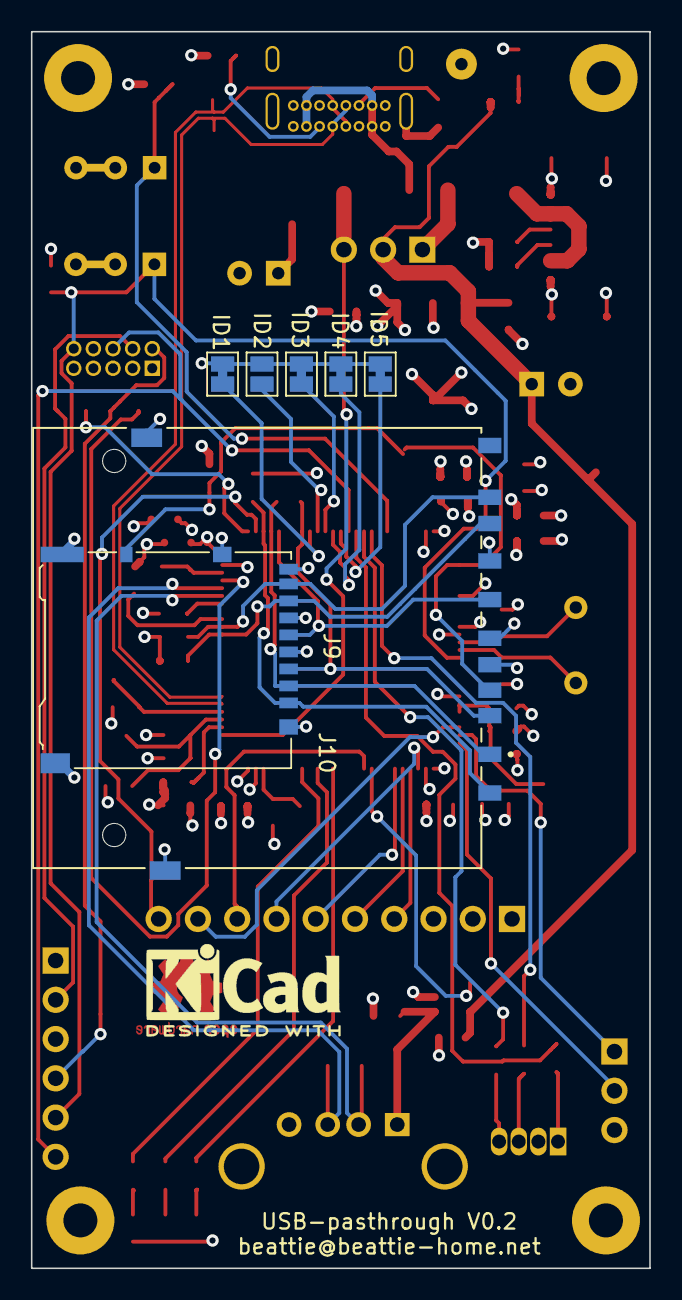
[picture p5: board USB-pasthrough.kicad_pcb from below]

Board: 4 copper layers, 40.0 x 80.0 mm, 98 parts (7 on the bottom side), 68 nets.

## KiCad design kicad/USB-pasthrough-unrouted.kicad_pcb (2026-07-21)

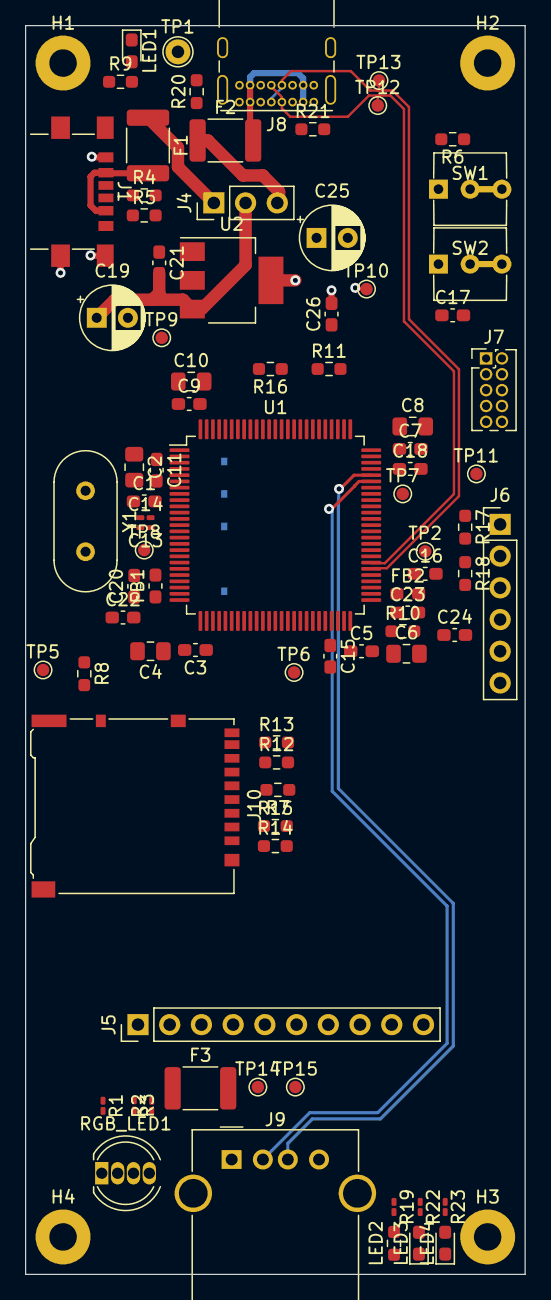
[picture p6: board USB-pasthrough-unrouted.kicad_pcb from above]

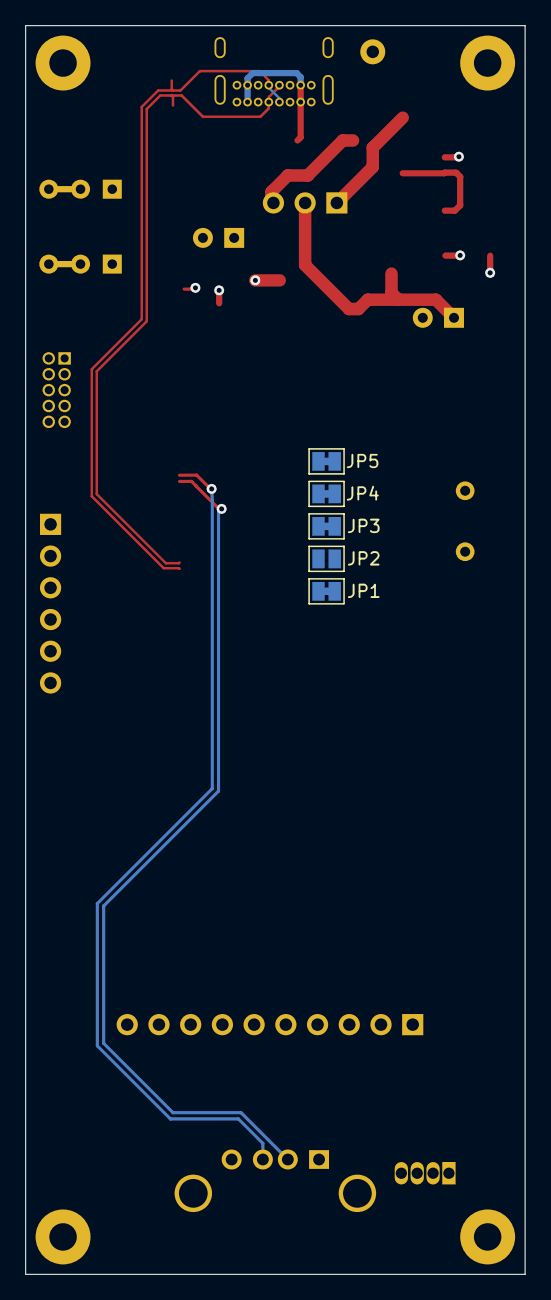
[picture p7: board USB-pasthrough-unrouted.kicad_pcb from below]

Board: 4 copper layers, 40.0 x 100.0 mm, 93 parts (5 on the bottom side), 71 nets.

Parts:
C1: 100nf; C_0603_1608Metric_Pad1.08x0.95mm_HandSolder
C2, C4, C6, C8, C10: 4.7uF; C_0805_2012Metric_Pad1.18x1.45mm_HandSolder
C3, C5, C7, C9, C11, C17, C21, C22, C24, C26: 100nF; C_0603_1608Metric_Pad1.08x0.95mm_HandSolder
C13, C14: 27pF; C_0201_0603Metric_Pad0.64x0.40mm_HandSolder
C15, C16, C18: 2.2uF; C_0603_1608Metric_Pad1.08x0.95mm_HandSolder
C19, C25: 10uF; CP_Radial_D5.0mm_P2.50mm
C20, C23: 1uF; C_0603_1608Metric_Pad1.08x0.95mm_HandSolder
F1, F2, F3: F; Fuse_1812_4532Metric_Pad1.30x3.40mm_HandSolder
FB1, FB2: 600@100MHz; L_0603_1608Metric_Pad1.05x0.95mm_HandSolder
H1, H2, H3, H4: MountingHole; MountingHole_2.2mm_M2_Pad
J1: USB_Power; USB_C_Receptacle_GCT_USB4135-GF-A_6P_TopMnt_Horizontal
J4: Power_Sel; PinHeader_1x03_P2.54mm_Vertical
J5: SPI Display; PinHeader_1x10_P2.54mm_Vertical
J6: SWD; PinHeader_1x06_P2.54mm_Vertical
J7: Cortex Debug; PinHeader_2x05_P1.27mm_Vertical
J8: USB_C; USB_C_Receptacle_GCT_USB4085
J9: USB_A; USB_A_Molex_67643_Horizontal
J10: MicroSD; microSD_HC_Hirose_DM3AT-SF-PEJM5
JP1: ID0; SolderJumper-2_P1.3mm_Bridged_Pad1.0x1.5mm
JP2: ID1; SolderJumper-2_P1.3mm_Open_Pad1.0x1.5mm
JP3: ID2; SolderJumper-2_P1.3mm_Bridged_Pad1.0x1.5mm
JP4: ID3; SolderJumper-2_P1.3mm_Bridged_Pad1.0x1.5mm
JP5: ID4; SolderJumper-2_P1.3mm_Bridged_Pad1.0x1.5mm
LED1: RED; LED_0603_1608Metric_Pad1.05x0.95mm_HandSolder
LED2: BLUE; R_0603_1608Metric_Pad0.98x0.95mm_HandSolder
LED3: GREEN; LED_0603_1608Metric_Pad1.05x0.95mm_HandSolder
LED4: YELLOW; LED_0603_1608Metric_Pad1.05x0.95mm_HandSolder
R1, R23: 150; R_0201_0603Metric_Pad0.64x0.40mm_HandSolder
R2, R22: 68; R_0201_0603Metric_Pad0.64x0.40mm_HandSolder
R3, R19: 33; R_0201_0603Metric_Pad0.64x0.40mm_HandSolder
R4, R5, R20, R21: 5.1K; R_0603_1608Metric_Pad0.98x0.95mm_HandSolder
R6: 10K; R_0603_1608Metric_Pad0.98x0.95mm_HandSolder
R7, R8, R12, R13, R14, R15: 47K; R_0603_1608Metric_Pad0.98x0.95mm_HandSolder
R9: 330; R_0603_1608Metric_Pad0.98x0.95mm_HandSolder
R10: 12K; R_0603_1608Metric_Pad0.98x0.95mm_HandSolder
R11: 100K; R_0603_1608Metric_Pad0.98x0.95mm_HandSolder
R16: 220k; R_0603_1608Metric_Pad0.98x0.95mm_HandSolder
R17, R18: 100; R_0603_1608Metric_Pad0.98x0.95mm_HandSolder
RGB_LED1: Status; LED_D5.0mm-4_RGB
SW1: Boot0; SW_Push_6mm_2pin_5.08mm
SW2: Reset; SW_Push_6mm_2pin_5.08mm
TP1: GND; TestPoint_THTPad_D2.0mm_Drill1.0mm
TP2: V12PHYHS; TestPoint_Pad_D1.0mm
TP5: MMC1_CDET; TestPoint_Pad_D1.0mm
TP6: VCAP_1; TestPoint_Pad_D1.0mm
TP7: VCAP_2; TestPoint_Pad_D1.0mm
TP8: VDDA; TestPoint_Pad_D1.0mm
TP9: +5V; TestPoint_Pad_D1.0mm
TP10: +3V3; TestPoint_Pad_D1.0mm
TP11: SWDIO; TestPoint_Pad_D1.0mm
TP12: USBC+; TestPoint_Pad_D1.0mm
TP13: USBC-; TestPoint_Pad_D1.0mm
TP14: USBA-; TestPoint_Pad_D1.0mm
TP15: USBA+; TestPoint_Pad_D1.0mm
U1: STM32F723VET6; LQFP-100_14x14mm_P0.5mm
U2: AMS1117; SOT-223-3_TabPin2
Y1: 8 MHz; Crystal_HC49-U_Vertical

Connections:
+3V3: C1.2, C3.1, C5.1, C7.1, C9.2, C11.2, C25.1, C26.2, FB1.1, FB2.2, J5.3, J6.1, J7.1, J10.4 (VDD), R7.1, R8.1, R12.2, R13.2, R14.2, R15.2, SW1.2, TP10.1, U1.6 (VBAT), U1.11 (VDD), U1.27 (VDD), U1.50 (VDD), U1.75 (VDD), U1.100 (VDD), U2.2 (VO)
+5V: C19.1, C21.2, F3.1, J4.2, R9.1, TP9.1, U2.3 (VI)
/ID0: JP1.1 (A), U1.41 (PE11)
/ID1: JP2.1 (A), U1.42 (PE12)
/ID2: JP3.1 (A), U1.43 (PE13)
/ID3: JP4.1 (A), U1.44 (PE14)
/ID4: JP5.1 (A), U1.45 (PE15)
/LCD_BL: J5.10, U1.77 (PA15)
/LCD_CS: J5.7, U1.28 (PA4)
/LCD_DC: J5.8, U1.67 (PA8)
/LCD_RST: J5.9, U1.69 (PA10)
/LED2: R19.1, U1.97 (PE0)
/LED3: R22.1, U1.98 (PE1)
/LED4: R23.1, U1.1 (PE2)
/LED5_B: R3.2, U1.92 (PB6)
/LED5_G: R2.2, U1.91 (PB5)
/LED5_R: R1.1, U1.90 (PB4)
/MMC1_CDET: J10.10 (DET_A), R8.2, TP5.1, U1.2 (PE3)
/MMC1_CLK: J10.5 (CLK), U1.80 (PC12)
/MMC1_CMD: J10.3 (CMD), R7.2, U1.83 (PD2)
/MMC1_D0: J10.7 (DAT0), R12.1, U1.65 (PC8)
/MMC1_D1: J10.8 (DAT1), R13.1, U1.66 (PC9)
/MMC1_D2: J10.1 (DAT2), R14.1, U1.78 (PC10)
/MMC1_D3: J10.2 (DAT3/CD), R15.1, U1.79 (PC11)
/PA13: R17.1, U1.72 (PA13)
/PA14: R18.1, U1.76 (PA14)
/SPI1_MISO: J5.5, U1.30 (PA6)
/SPI1_MOSI: J5.6, U1.31 (PA7)
/SPI1_SCK: J5.4, U1.29 (PA5)
/SWCLK: J6.3, J7.4, R18.2
/SWDIO: J6.2, J7.2, R17.2, TP11.1
/SWO: J6.4, J7.6, U1.89 (PB3)
/USBA+: J9.3 (D+), TP15.1, U1.71 (PA12)
/USBA-: J9.2 (D-), TP14.1, U1.70 (PA11)
/USBC+: J8.A6 (D+), J8.B6 (D+), TP12.1, U1.57 (PB15)
/USBC-: J8.A7 (D-), J8.B7 (D-), TP13.1, U1.56 (PB14)
/V12PHYHS: C16.1, TP2.1, U1.55 (V12PHYHS)
/VBUS_DATA: F2.1, J4.3, R11.1, R16.1
/VBUS_PWR: F1.1, J4.1
/VCAP_1: C15.1, TP6.1, U1.48 (VCAP_1)
/VCAP_2: C18.1, TP7.1, U1.73 (VCAP_2)
/VDDA: C20.2, FB1.2, TP8.1, U1.20 (VREF+), U1.21 (VDDA)
/nRESET: C17.1, J6.5, J7.10, SW2.1, U1.14 (NRST)
GND: C2.1, C4.2, C6.2, C8.1, C10.2, C11.1, C13.2, C14.1, C15.2, C16.2, C17.2, C18.2, C19.2, C21.1, C22.1, C24.2, C25.2, C26.1, J1.A12 (GND), J1.B12 (GND), J1.S1 (SHIELD), J5.1, J6.6, J7.3, J7.5, J7.9, J8.A1 (GND), J8.A12 (GND), J8.B1 (GND), J8.B12 (GND), J8.S1 (SHIELD), J9.4 (GND), J9.5 (Shield), J10.6 (VSS), J10.9 (DET_B), J10.11 (SHIELD), JP1.2 (B), JP2.2 (B), JP3.2 (B), JP4.2 (B), JP5.2 (B), LED1.1 (K), LED2.1 (K), LED3.1 (K), LED4.1 (K), R4.2, R5.2, R6.1, R10.2, R16.2, R20.1, R21.2, RGB_LED1.2 (K), SW2.2, TP1.1, U1.10 (VSS), U1.19 (VSSA), U1.26 (VSS), U1.49 (VSS), U1.74 (VSS), U1.99 (VSS), U2.1 (ADJ)
unnamed: C1.1, C2.2
unnamed: C3.2, C4.1
unnamed: C5.2, C6.1
unnamed: C7.2, C8.2
unnamed: C9.1, C10.1
unnamed: C13.1, U1.13 (PH1), Y1.2
unnamed: C14.2, U1.12 (PH0), Y1.1
unnamed: C20.1, C22.2
unnamed: C23.1, FB2.1, U1.54 (VDDPHYHS)
unnamed: C23.2, C24.1
unnamed: F1.2, J1.A9 (VBUS), J1.B9 (VBUS)
unnamed: F2.2, J8.A4 (VBUS), J8.A9 (VBUS), J8.B4 (VBUS), J8.B9 (VBUS)
unnamed: F3.2, J9.1 (VBUS)
unnamed: J1.A5 (CC1), R4.1
unnamed: J1.B5 (CC2), R5.1
unnamed: J8.A5 (CC1), R21.1
unnamed: J8.B5 (CC2), R20.2
unnamed: LED1.2 (A), R9.2
unnamed: LED2.2 (A), R19.2
unnamed: LED3.2 (A), R22.2
unnamed: LED4.2 (A), R23.2
unnamed: R1.2, RGB_LED1.1 (RA)
unnamed: R2.1, RGB_LED1.4 (GA)
unnamed: R3.1, RGB_LED1.3 (BA)
unnamed: R6.2, SW1.1, U1.94 (BOOT0)
unnamed: R10.1, U1.53 (REXTPHYHS)
unnamed: R11.2, U1.68 (PA9)

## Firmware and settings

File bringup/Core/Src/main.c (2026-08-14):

#include "main.h"
#include "gpio.h"
#include "sdmmc.h"
#include "spi.h"
#include "st7735.h"
#include "usb_host.h"
#include "usbh_hid.h"
#include "usb_device.h"
#include "usbd_hid.h"
#include <stdio.h>
#include <string.h>

void SystemClock_Config(void);
static void MPU_Config(void);
static void USART2_Init(void);
static void sd_pin_test(void);

UART_HandleTypeDef huart2;

/* v0.2 LED chase: PE9=BLUE, PE11=GREEN, PE13=YELLOW, PB4=RGB_R, PB5=RGB_G, PB6=RGB_B */
static const struct { GPIO_TypeDef *port; uint16_t pin; const char *name; } leds[] = {
    { GPIOE, GPIO_PIN_9,  "PE9  BLUE"  },
    { GPIOE, GPIO_PIN_11, "PE11 GREEN" },
    { GPIOE, GPIO_PIN_13, "PE13 YELLOW"},
    { GPIOB, GPIO_PIN_4,  "PB4  RGB_R" },
    { GPIOB, GPIO_PIN_5,  "PB5  RGB_G" },
    { GPIOB, GPIO_PIN_6,  "PB6  RGB_B" },
};
#define NUM_LEDS (sizeof(leds)/sizeof(leds[0]))

int main(void)
{
    MPU_Config();
    HAL_Init();
    SystemClock_Config();

    MX_GPIO_Init();
    USART2_Init();
    setvbuf(stdout, NULL, _IONBF, 0);  /* disable stdio buffering — flush every printf immediately */
    printf("GPIO ok — SYSCLK=%lu PCLK1=%lu PCLK2=%lu Hz\r\n",
        HAL_RCC_GetSysClockFreq(), HAL_RCC_GetPCLK1Freq(), HAL_RCC_GetPCLK2Freq());
    MX_SPI1_Init();
    ST7735_Unselect();
    ST7735_Init();
    ST7735_FillScreen(ST7735_BLACK);
    ST7735_WriteString(0, 0, "STM32F723", Font_11x18, ST7735_WHITE, ST7735_BLACK);
    ST7735_WriteString(0, 20, "v0.2 OK", Font_7x10, ST7735_GREEN, ST7735_BLACK);
    printf("Display ok\r\n");

    MX_USB_HOST_Init();
    HAL_Delay(500);  /* let TPS2065C/device settle before first enumeration attempt */
    printf("USB-A host started — plug keyboard\r\n");

    MX_USB_DEVICE_Init();
    printf("USB-C device started (OTG_HS OTGPHYC) — plug to PC\r\n");

    sd_pin_test();

    MX_SDMMC1_SD_Init();
    {
        HAL_SD_CardInfoTypeDef info;
        HAL_SD_GetCardInfo(&hsd1, &info);
        HAL_SD_CardStateTypeDef cstate = HAL_SD_GetCardState(&hsd1);
        printf("SD state=%u err=%08lX cardstate=%u type=%u ver=%u blocks=%lu bsize=%lu\r\n",
            (unsigned)hsd1.State, hsd1.ErrorCode, (unsigned)cstate,
            (unsigned)info.CardType, (unsigned)info.CardVersion,
            info.BlockNbr, info.BlockSize);
        /* dump raw CSD from handle */
        printf("  RCA=%04lX CSD: %08lX %08lX %08lX %08lX\r\n",
            hsd1.SdCard.RelCardAdd,
            hsd1.CSD[0], hsd1.CSD[1], hsd1.CSD[2], hsd1.CSD[3]);
    }

    uint32_t disp_tick = 0;
    uint32_t disp_phase = 0;
    static const uint16_t colors[] = { ST7735_RED, ST7735_GREEN, ST7735_BLUE, ST7735_WHITE, ST7735_BLACK };
    uint32_t led_tick = 0;
    uint32_t led_phase = 0;
    uint32_t uart_tick = 0;
    uint32_t uart_count = 0;
    uint8_t rx_byte;

    while (1)
    {
        /* Display color cycle: new color every 2s */
        if (HAL_GetTick() - disp_tick >= 2000)
        {
            disp_tick = HAL_GetTick();
            ST7735_FillScreen(colors[disp_phase]);
            disp_phase = (disp_phase + 1) % 5;
        }

        /* LED chase at 250ms per phase */
        if (HAL_GetTick() - led_tick >= 250)
        {
            led_tick = HAL_GetTick();

            HAL_GPIO_WritePin(GPIOE, GPIO_PIN_9|GPIO_PIN_11|GPIO_PIN_13, GPIO_PIN_RESET);
            HAL_GPIO_WritePin(GPIOB, GPIO_PIN_4|GPIO_PIN_5|GPIO_PIN_6,   GPIO_PIN_RESET);

            HAL_GPIO_WritePin(leds[led_phase].port, leds[led_phase].pin, GPIO_PIN_SET);
            led_phase = (led_phase + 1) % NUM_LEDS;
        }

#ifdef UART_TICKS
        /* UART TX: send tick every second */
        if (HAL_GetTick() - uart_tick >= 1000)
        {
            uart_tick = HAL_GetTick();
            char buf[32];
            int len = snprintf(buf, sizeof(buf), "tick %lu\r\n", uart_count++);
            HAL_UART_Transmit(&huart2, (uint8_t *)buf, len, 10);
        }
#endif

        /* UART RX: echo any received byte */
        if (HAL_UART_Receive(&huart2, &rx_byte, 1, 0) == HAL_OK)
        {
            HAL_UART_Transmit(&huart2, &rx_byte, 1, 10);
        }

        /* USB-A host */
        MX_USB_HOST_Process();

        if (kbd_report_new)
        {
            kbd_report_new = 0;
            HID_KEYBD_Info_TypeDef *k = USBH_HID_GetKeybdInfo(&hUsbHostFS);
            if (k)
            {
                /* Build standard 8-byte boot keyboard HID report */
                uint8_t report[8];
                report[0] = (k->lctrl  << 0) | (k->lshift << 1) | (k->lalt  << 2) | (k->lgui  << 3) |
                            (k->rctrl  << 4) | (k->rshift << 5) | (k->ralt  << 6) | (k->rgui  << 7);
                report[1] = 0x00;
                memcpy(&report[2], k->keys, 6);

                USBD_HID_SendReport(&hUsbDeviceHS, report, sizeof(report));

                uint8_t ascii = USBH_HID_GetASCIICode(k);
                if (ascii)
                    printf("KEY: '%c' (0x%02X)\r\n", ascii, ascii);
                else if (k->keys[0])
                    printf("KEY: keycode=0x%02X\r\n", k->keys[0]);
            }
        }
    }
}

/* Step 2: HSE 25 MHz → PLL → SYSCLK=216 MHz, APB1=54 MHz, APB2=108 MHz, PLLQ=48 MHz */
void SystemClock_Config(void)
{
    __HAL_RCC_PWR_CLK_ENABLE();
    __HAL_PWR_VOLTAGESCALING_CONFIG(PWR_REGULATOR_VOLTAGE_SCALE1);

    RCC_OscInitTypeDef osc = {0};
    osc.OscillatorType      = RCC_OSCILLATORTYPE_HSE;
    osc.HSEState            = RCC_HSE_ON;
    osc.PLL.PLLState        = RCC_PLL_ON;
    osc.PLL.PLLSource       = RCC_PLLSOURCE_HSE;
    osc.PLL.PLLM            = 25;   /* 25 MHz / 25 = 1 MHz VCO input */
    osc.PLL.PLLN            = 432;  /* × 432 = 432 MHz VCO */
    osc.PLL.PLLP            = RCC_PLLP_DIV2;  /* 216 MHz SYSCLK */
    osc.PLL.PLLQ            = 9;    /* 48 MHz USB */
    if (HAL_RCC_OscConfig(&osc) != HAL_OK)
        Error_Handler();

    if (HAL_PWREx_EnableOverDrive() != HAL_OK)
        Error_Handler();

    RCC_ClkInitTypeDef clk = {0};
    clk.ClockType      = RCC_CLOCKTYPE_HCLK | RCC_CLOCKTYPE_SYSCLK |
                         RCC_CLOCKTYPE_PCLK1 | RCC_CLOCKTYPE_PCLK2;
    clk.SYSCLKSource   = RCC_SYSCLKSOURCE_PLLCLK;
    clk.AHBCLKDivider  = RCC_SYSCLK_DIV1;
    clk.APB1CLKDivider = RCC_HCLK_DIV4;
    clk.APB2CLKDivider = RCC_HCLK_DIV2;
    if (HAL_RCC_ClockConfig(&clk, FLASH_LATENCY_7) != HAL_OK)
        Error_Handler();
}

/* MPU: mark 0x00000000–0xFFFFFFFF no-access with sub-region exceptions for
 * SRAM and Flash, preventing speculative accesses to unmapped regions. */
static void MPU_Config(void)
{
    MPU_Region_InitTypeDef r = {0};
    HAL_MPU_Disable();
    r.Enable            = MPU_REGION_ENABLE;
    r.Number            = MPU_REGION_NUMBER0;
    r.BaseAddress       = 0x0;
    r.Size              = MPU_REGION_SIZE_4GB;
    r.SubRegionDisable  = 0x87;
    r.TypeExtField      = MPU_TEX_LEVEL0;
    r.AccessPermission  = MPU_REGION_NO_ACCESS;
    r.DisableExec       = MPU_INSTRUCTION_ACCESS_DISABLE;
    r.IsShareable       = MPU_ACCESS_SHAREABLE;
    r.IsCacheable       = MPU_ACCESS_NOT_CACHEABLE;
    r.IsBufferable      = MPU_ACCESS_NOT_BUFFERABLE;
    HAL_MPU_ConfigRegion(&r);
    HAL_MPU_Enable(MPU_PRIVILEGED_DEFAULT);
}


static void test_pin(GPIO_TypeDef *port, uint16_t pin, const char *name)
{
    GPIO_InitTypeDef g = {0};
    g.Pin = pin; g.Mode = GPIO_MODE_INPUT; g.Speed = GPIO_SPEED_FREQ_LOW;

    g.Pull = GPIO_PULLUP;   HAL_GPIO_Init(port, &g); HAL_Delay(1);
    int hi = HAL_GPIO_ReadPin(port, pin);
    g.Pull = GPIO_PULLDOWN; HAL_GPIO_Init(port, &g); HAL_Delay(1);
    int lo = HAL_GPIO_ReadPin(port, pin);

    const char *result = (hi == 1 && lo == 0) ? "OK (floating)" :
                         (hi == 1 && lo == 1) ? "STUCK HIGH"    :
                         (hi == 0 && lo == 0) ? "STUCK LOW"     : "?";
    printf("  %-10s hi=%d lo=%d  %s\r\n", name, hi, lo, result);
}

static void sd_pin_test(void)
{
    __HAL_RCC_GPIOC_CLK_ENABLE();
    printf("SD pin test (no card):\r\n");
    test_pin(GPIOC, GPIO_PIN_8,  "PC8  D0");
    test_pin(GPIOC, GPIO_PIN_9,  "PC9  D1");
    test_pin(GPIOC, GPIO_PIN_10, "PC10 D2");
    test_pin(GPIOC, GPIO_PIN_11, "PC11 D3");
    test_pin(GPIOC, GPIO_PIN_12, "PC12 CLK");
    test_pin(GPIOD, GPIO_PIN_2,  "PD2  CMD");
    test_pin(GPIOE, GPIO_PIN_3,  "PE3  CDET");
    printf("SD pin test done\r\n");
}

/* USART2: PA2=TX (AF7), PA3=RX (AF7), 115200 8N1 — v0.2 debug header */
static void USART2_Init(void)
{
    __HAL_RCC_USART2_CLK_ENABLE();

    GPIO_InitTypeDef g = {0};
    g.Pin       = GPIO_PIN_2 | GPIO_PIN_3;
    g.Mode      = GPIO_MODE_AF_PP;
    g.Pull      = GPIO_NOPULL;
    g.Speed     = GPIO_SPEED_FREQ_VERY_HIGH;
    g.Alternate = GPIO_AF7_USART2;
    HAL_GPIO_Init(GPIOA, &g);

    huart2.Instance          = USART2;
    huart2.Init.BaudRate     = 115200;
    huart2.Init.WordLength   = UART_WORDLENGTH_8B;
    huart2.Init.StopBits     = UART_STOPBITS_1;
    huart2.Init.Parity       = UART_PARITY_NONE;
    huart2.Init.Mode         = UART_MODE_TX_RX;
    huart2.Init.HwFlowCtl   = UART_HWCONTROL_NONE;
    huart2.Init.OverSampling = UART_OVERSAMPLING_16;
    if (HAL_UART_Init(&huart2) != HAL_OK)
        Error_Handler();

    /* Direct register smoke test — confirms PA2 TX path before stdio init */
    const char *hw = "\r\nUART2 HW OK\r\n";
    for (const char *p = hw; *p; p++) {
        while (!(USART2->ISR & USART_ISR_TXE));
        USART2->TDR = (uint8_t)*p;
    }
}

void Error_Handler(void)
{
    __disable_irq();
    while (1) { }
}

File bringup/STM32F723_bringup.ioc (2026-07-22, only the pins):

Mcu.UserName=STM32F723VETx
PA11.Signal=USB_OTG_FS_DM
PA12.Signal=USB_OTG_FS_DP
PA13.Signal=SYS_JTMS-SWDIO
PA14.Signal=SYS_JTCK-SWCLK
PA5.Signal=SPI1_SCK
PA6.Signal=SPI1_MISO
PA7.Signal=SPI1_MOSI
PB14.Signal=USB_OTG_HS_DM
PB15.Signal=USB_OTG_HS_DP
PB3.Signal=SYS_JTDO-SWO
PB8.Signal=SDMMC1_D4
PB9.Signal=SDMMC1_D5
PC10.Signal=SDMMC1_D2
PC11.Signal=SDMMC1_D3
PC12.Signal=SDMMC1_CK
PC6.Signal=SDMMC1_D6
PC7.Signal=SDMMC1_D7
PC8.Signal=SDMMC1_D0
PC9.Signal=SDMMC1_D1
PD2.Signal=SDMMC1_CMD
PE0.Signal=GPIO_Output
PE1.Signal=GPIO_Output
PE11.Signal=GPIO_Input
PE12.Signal=GPIO_Input
PE13.Signal=GPIO_Input
PE14.Signal=GPIO_Input
PE15.Signal=GPIO_Input
PE2.Signal=GPIO_Output
PE3.Signal=GPIO_Input
PH0-OSC_IN.Signal=RCC_OSC_IN
PH1-OSC_OUT.Signal=RCC_OSC_OUT

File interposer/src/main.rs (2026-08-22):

#![no_std]
#![no_main]

mod pm;

use defmt::info;
use defmt_rtt as _;
use embassy_executor::Spawner;
use core::sync::atomic::{AtomicBool, AtomicU8, Ordering};
use core::fmt::Write;

use heapless::String;

use embassy_futures::select::{select, Either};

use embassy_stm32::Peri;
use embassy_stm32::gpio::{AfType, Flex, Level, Output, OutputType};
// rename Speed to avoid clash with USB Speed:
use embassy_stm32::gpio::Speed as GpioSpeed;
use embassy_stm32::gpio::{Input, Pull};
use embassy_stm32::{interrupt, pac};
use embassy_stm32::bind_interrupts;
use embassy_stm32::interrupt::typelevel::Handler;
use embassy_stm32::interrupt::typelevel::Interrupt;
use embassy_stm32::rcc::{
    AHBPrescaler, APBPrescaler, Hse, HseMode, Pll, PllMul, PllPDiv,
    PllPreDiv, PllQDiv, PllSource, Sysclk,
};
use embassy_stm32::time::Hertz;
use embassy_stm32::Config;
use embassy_stm32::sdmmc::{Sdmmc, Config as SdmmcConfig};
use embassy_stm32::sdmmc::sd::{StorageDevice, CmdBlock, Addressable, Card, DataBlock};

use embassy_stm32::usb::InterruptHandler as UsbInterruptHandler;
use embassy_stm32::usb::Driver as UsbDriver;

use embassy_usb::class::hid::{
    HidWriter,
    HidSubclass,
    HidBootProtocol,
    Config as HidConfig,
    State as HidState,
};

use embassy_usb_synopsys_otg::{PhyType, otg_v1::Otg};
use embassy_usb_synopsys_otg::host::{
    HostState,
    OtgHost,
    OtgHostInstance,
    on_host_interrupt,
};
use embassy_usb_synopsys_otg::host::OtgHostAllocator;

use embassy_usb_host::{BusState, BusRoute, bus};
use embassy_usb_host::class::kbd::{KbdEvent, KbdHandler};
use embassy_usb_host::handler::HandlerEvent;
use embassy_usb_host::{BusController, BusHandle};

use embassy_sync::signal::Signal;
use embassy_sync::blocking_mutex::raw::CriticalSectionRawMutex;
use embassy_sync::channel::Channel;

use static_cell::StaticCell;

use embassy_time::Timer;

use block_device_driver::{BlockDevice};

use mipidsi::interface::SpiInterface;   // Provides builder for DisplayInterface
use mipidsi::{Builder,                  // Provides builder for Display
    options::ColorOrder,
    models::ST7735s
};
use embedded_graphics::{prelude::*, pixelcolor::Rgb565};    // Color type
use embedded_graphics::text::Text;
use embedded_graphics::{mono_font::{ ascii:: FONT_5X7}};
use embedded_graphics::{mono_font::{ ascii:: FONT_7X14}};
use embedded_graphics::mono_font::{MonoTextStyle, MonoTextStyleBuilder};
use embedded_graphics::text::{Baseline, TextStyleBuilder};

use aligned::{Aligned, A4};

use panic_probe as _;

mod msc;
static MSC:         StaticCell<msc::Msc<'static, HsDriver>> = StaticCell::new();
static MSC_CONTROL: StaticCell<msc::MscControl>             = StaticCell::new();

defmt::timestamp!("{=u64:us}", embassy_time::Instant::now().as_micros());

type HsDriver = UsbDriver<'static, embassy_stm32::peripherals::USB_OTG_HS>;

static HW_VERSION: AtomicU8 = AtomicU8::new(0);

enum DisplayCmd {
    WriteLine(u8, heapless::String<26>),    // row, text
    Clear,
}

static DISPLAY_CHANNEL: Channel<CriticalSectionRawMutex, DisplayCmd, 4> =
        Channel::new();

#[derive(Clone, Copy)]
enum LedCmd {
    KeyboardConnected,
    KeyboardDisconnected,
    NotAKeyboard,
}

static LED_CMD: Signal<CriticalSectionRawMutex, LedCmd> = Signal::new();

static HOST_STATE: HostState<8> = HostState::new();
static BUS_STATE: BusState = BusState::new();

static EP_OUT_BUF:      StaticCell<[u8; 1024]>  = StaticCell::new();
static DEV_DESC:        StaticCell<[u8; 256]>   = StaticCell::new();
static CONF_DESC:       StaticCell<[u8; 256]>   = StaticCell::new();
static BOS_DESC:        StaticCell<[u8; 64]>    = StaticCell::new();
static MSOS_DESC:       StaticCell<[u8; 64]>    = StaticCell::new();
static HID_STATE:       StaticCell<HidState>    = StaticCell::new();

static HID_KEYBOARD_REPORT_DESC: &[u8] = &[
    0x05, 0x01,  // Usage Page (Generic Desktop)
    0x09, 0x06,  // Usage (Keyboard)
    0xA1, 0x01,  // Collection (Application)
    0x05, 0x07,  //   Usage Page (Key Codes)
    0x19, 0xE0,  //   Usage Minimum (224) — modifier keys
    0x29, 0xE7,  //   Usage Maximum (231)
    0x15, 0x00,  //   Logical Minimum (0)
    0x25, 0x01,  //   Logical Maximum (1)
    0x75, 0x01,  //   Report Size (1 bit)
    0x95, 0x08,  //   Report Count (8) — 8 modifier bits
    0x81, 0x02,  //   Input (Data, Variable, Absolute)
    0x95, 0x01,  //   Report Count (1)
    0x75, 0x08,  //   Report Size (8 bits) — reserved byte
    0x81, 0x01,  //   Input (Constant)
    0x95, 0x06,  //   Report Count (6)
    0x75, 0x08,  //   Report Size (8 bits) — 6 keycodes
    0x15, 0x00,  //   Logical Minimum (0)
    0x25, 0x65,  //   Logical Maximum (101)
    0x05, 0x07,  //   Usage Page (Key Codes)
    0x19, 0x00,  //   Usage Minimum (0)
    0x29, 0x65,  //   Usage Maximum (101)
    0x81, 0x00,  //   Input (Data, Array)
    0xC0,        // End Collection
];

static CARD_PRESENT: AtomicBool = AtomicBool::new(false);

struct OtgFsHostIrq;

struct MscSd<'a, 'b> {
    dev: StorageDevice<'a, 'b, Card>,
    capacity: u32,
}

impl<'a, 'b> msc::SdAccess for MscSd<'a, 'b> {
    async fn read_sector(&mut self, lba: u32, buf: &mut [u8; 512]) -> bool {
        let mut block = DataBlock::new();
        if self.dev.read_block(lba, &mut block).await.is_err() {
            return false;
        }
        for (i, word) in block.0.iter().enumerate() {
            buf[i*4..i*4+4].copy_from_slice(&word.to_le_bytes());
        }
        true
    }
    fn is_present(&self) -> bool {
        CARD_PRESENT.load(Ordering::Relaxed)
    }
    async fn write_sector(&mut self, lba: u32, buf: &[u8; 512]) -> bool {
        let mut block = DataBlock::new();
        for (i, word) in block.0.iter_mut().enumerate() {
            *word = u32::from_le_bytes(buf[i*4..i*4+4].try_into().unwrap());
        }
        self.dev.write_block(lba, &block).await.is_ok()
    }
    fn capacity_sectors(&self) -> u32 { self.capacity }
}

impl Handler<interrupt::typelevel::OTG_FS> for OtgFsHostIrq {
    unsafe fn on_interrupt() {
        let r = unsafe { Otg::from_ptr(pac::USB_OTG_FS.as_ptr() as *mut ()) };
        on_host_interrupt(r, &HOST_STATE, 8);
    }
}

bind_interrupts!(struct Irqs {
    OTG_FS => OtgFsHostIrq;
    OTG_HS => UsbInterruptHandler<embassy_stm32::peripherals::USB_OTG_HS>;
    SDMMC1 => embassy_stm32::sdmmc::InterruptHandler<
            embassy_stm32::peripherals::SDMMC1>;
    DMA2_STREAM3 => embassy_stm32::dma::InterruptHandler<
            embassy_stm32::peripherals::DMA2_CH3>;
});
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

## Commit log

2026-04-24 Initial skeleton for STM32F723 passthrough demo
    [USB-pasthrough.kicad_pcb, USB-pasthrough.kicad_sch]
2026-04-24 Pickup latest ( match gerbers/USB-passthrough.zip)
    [USB-pasthrough.kicad_pcb, USB-pasthrough.kicad_sch]
2026-04-24 Pickup files missed in initial skeleton
    [main.rs]
2026-05-08 Update TP1 footprint to smaller THT test point
    [USB-pasthrough.kicad_sch]
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2026-05-08 Cleanup for v0.2 PBC
    [USB-pasthrough.kicad_pcb]
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2026-05-09 Resolve DRC errors on unrouted PCB
    [USB-pasthrough.kicad_pcb]
2026-05-09 Add initial v0.2 PCB layout, unrouted
    [USB-pasthrough-unrouted.kicad_pcb]
2026-05-10 Update schematic
    Change JP2 to Open to reflect v0.2
    [USB-pasthrough.kicad_sch]
2026-05-10 Generate clean unrouted PCB
    1. place components
    2. manually route USB differential signals
    3. manually route Power Supply
    4. connect 3V3 and GND to energize power planes
    [USB-pasthrough-unrouted.kicad_pcb]
2026-05-10 Capture routed PCB
    1. results of FreeRouting
    2. manually tweak routing
    3. route/connect 3V3 and GND
    [USB-pasthrough_routed.kicad_pcb]
2026-05-10 Update LED 2 footprint
    [USB-pasthrough.kicad_sch]
2026-05-10 Tweak PCB
    1. Import LED2 footprint update
    2. Move TP8
    3. Adjust silkscreen
    [USB-pasthrough.kicad_pcb]
2026-05-10 Tweak PCB
    1. adjust some signals
    2. Increase the size of the +5V trace to the USBA connector
    [USB-pasthrough.kicad_pcb]
2026-05-11 Update PCB
    1. Move SD socket to bottom of board (to reduce size of PCB)
    2. Reduce size of PCB
    3. reroute traces
    [USB-pasthrough.kicad_pcb]
2026-05-11 Tweak PCD and slikscreen
    1. Reroute traces to clear Xtal footprint
    2. Label pins on SWD header (move resistors)
    [USB-pasthrough.kicad_pcb]
2026-05-11 Realign pin 1 of components, up and left
    [USB-pasthrough.kicad_pcb, USB-pasthrough.kicad_sch]
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2026-05-12 Rework ID jumper labeling
    [USB-pasthrough.kicad_pcb, USB-pasthrough.kicad_sch]
2026-05-12 Reannotate based on position on PCB
    [USB-pasthrough.kicad_pcb, USB-pasthrough.kicad_sch]
2026-05-12 Fix ID jumper references
    [USB-pasthrough.kicad_pcb, USB-pasthrough.kicad_sch]
2026-05-12 Add labels to Boot0 and Reset buttons
    [USB-pasthrough.kicad_pcb]
2026-05-12 Reroute SWDIO trace that was awkward
    [USB-pasthrough.kicad_pcb]
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2026-05-21 Add U1 pi 1 mark
    [USB-pasthrough.kicad_pcb]
2026-05-22 Change incorrect metric footprints to imperial
    [USB-pasthrough.kicad_pcb, USB-pasthrough.kicad_sch]
2026-05-31 Clean up SWD connector
    Make pins conform to Nucleo connector
    Rename SoC to R signals
    [USB-pasthrough.kicad_sch]
2026-06-19 Fix problem with bypass caps on VDDA and VDDPHYHS
    [USB-pasthrough.kicad_sch]
2026-06-26 fix capacitor footprints
    [USB-pasthrough.kicad_sch]
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2026-07-11 Tweak ID names, add serial port
    [USB-pasthrough.kicad_sch]
2026-07-17 Start switching to Full Sized SD socket
    The uSD socket is too small, use bigger socket for easier
    soldering.
    [USB-pasthrough.kicad_sch]
2026-07-18 Add fulsized SD Card connector serial etc...
    Add KiCad symbol and footprint for SD Card connector to try out
    overlaying Full size and uSD connectors allowing support for either
    one depending on which connector is installed.
    Also add SMD USB A connector for possible use in place of THT.
    [USB-pasthrough.kicad_pcb, USB-pasthrough.kicad_sch]
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2026-07-18 Rename MMC1_* signals to SD1_* in schematic and CLAUDE.md
    [USB-pasthrough.kicad_sch]
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2026-07-19 First Pass v0.2 schematic
    [USB-pasthrough.kicad_pcb, USB-pasthrough.kicad_sch]
2026-07-20 Test routing, many courtyard conflicts
    [USB-pasthrough.kicad_pcb, USB-pasthrough.kicad_sch]
2026-07-20 V0.2 layout pending bring-up
    [USB-pasthrough.kicad_pcb, USB-pasthrough.kicad_sch]
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2026-07-21 Update CLAUDE.md: USB-A host bring-up complete, fix toolchain/flash notes
    - Mark USB-A host done: AnnePro2 enumerates, URB_DONE on keypress confirmed
    - Add USB-C and MicroSD status notes with v0.2 blockers
    - Update toolchain: 8MHz crystal installed, HSE clock config documented
    - Fix flash/attach commands to point at STM32F723_bringup build output
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2026-07-21 Schematic: add TPS2065C USB-A VBUS switch, remove PA9 VBUS divider
    - Add TPS2065C (via TPS2041B symbol) on USB-A VBUS: IN=5V, OUT=USBA_VBUS,
    EN=PB0 (active-high, GPIO-low at reset keeps VBUS off)
    - Remove VBUS_DATA voltage divider on PA9 (no longer needed)
    [USB-pasthrough.kicad_sch]
2026-07-21 Schematic: move LCD_DC to PB1, add PA8 test point, add TPS2065C symbol
    - LCD_DC moved from PA8 to PB1 (avoids PA9 OTG_FS_VBUS analog path concern)
    - PA8 broken out as test point (MCO1/OTG_FS_SOF available for probing)
    - Add TPS2065C symbol (copied from TPS2041B, SOT-23-5 footprint retained)
    - Update sym-lib-table to include project TPS2065C library
    - Update CLAUDE.md GPIO map: LCD_DC → PB1, PA8 → test point
    [USB-pasthrough.kicad_sch]
2026-07-21 Schematic and Layout for v0.2
    [USB-pasthrough.kicad_pcb, USB-pasthrough.kicad_sch]
2026-07-21 Schematic/PCB: connect PB13 to VBUS_DATA for OTG_HS VBUS sense
    Completes v0.2 change list item 2 — enables OTG_HS VBUS comparator
    so USB-C device D+ pull-up activates when VBUS is present.
    [USB-pasthrough.kicad_pcb, USB-pasthrough.kicad_sch]
2026-07-21 Schematic/PCB: update signal names and complete PB13 VBUS_DATA routing
    [USB-pasthrough.kicad_pcb, USB-pasthrough.kicad_sch]
2026-07-21 ERC: exclude mounting hole GND power-pin-not-driven warnings
    [USB-pasthrough.kicad_sch]
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2026-07-22 Clean up main.c and usb_host.h: strip CubeMX boilerplate
    - Remove CubeMX file header and all USER CODE BEGIN/END markers
    - Move extern Appli_state/hUsbHostFS to usb_host.h (proper place)
    - Clean up usb_host.h: strip doxygen groups, add missing externs
    - Simplify SystemClock_Config and MPU_Config local var names
    - make test_pin static, tighten formatting throughout
    [main.c]
2026-07-22 Fix USB-A HID keyboard receive for AnnePro2 (report protocol, 37-byte IN)
    Two ST middleware bugs prevented USBH_HID_EventCallback from ever firing:
    1. usbh_hid.c: HID_Handle->length/ep_addr were initialised from Ep_Desc[0],
    which is the OUT endpoint (EP 0x01, mps=4) on the AnnePro2. Polling
    requested 4 bytes from EP 0x82 (mps=37) → BABBLE → XferSize=0 → callback
    never fired. Fix: override length/ep_addr with IN endpoint values in the
    same loop that opens the IN pipe.
    2. usbh_hid_keybd.h: USBH_HID_KEYBD_REPORT_SIZE was 8, so keybd_rx_report_buf
    was only 8 bytes — far too small for 37-byte report-protocol reports. Set
    to 40 (10×40=400 < MAX_DATA_BUFFER=512; 37<40 s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
    [main.c]
2026-07-22 OTG_HS: enable VBUS sensing now PB13 is bodged to VBUS_DATA
    Enable vbus_sensing_enable and remove BVALOEN/BVALOVAL bypass.
    PB13 bodge wire connects VBUS_DATA to STM32 VBUS comparator input;
    BSESVLD=1 confirmed. VDDPHYHS=0V identified as root cause of D+ not
    pulling up — FB2 needs reflow/replacement.
2026-07-23 Add v0.2 gerbers and update PCB with silkscreen marks
    [USB-pasthrough.kicad_pcb, USB-pasthrough.kicad_sch]
2026-07-23 Sync bringup firmware and fix schematic for v0.2 bring-up
    Bringup firmware (synced from ~/STM32F723_bringup):
    - Remove PB15 GPIO test (was confusing USB host before PHY ready)
    - Add GOTGCTL + DCTL to 2s status loop for ISR-safe debug
    - VBDEN=1 empirically required for internal FS transceiver to drive D+
    - BVALOEN+BVALOVAL=1 alongside VBDEN
    - Fix PHY clock gate: only gate when low_power_enable=1
    - OTG_HS IRQ priority 5, OTG_FS priority 6 (SWD/DAP preemption)
    - rst=1 (ENUMDONE) confirmed on hub; v0.1 D+ trace physically broken
    Schematic (post-fab corrections, not in v0.2-fab-send):
    - Crystal label updated to 25 MHz (OTGPHYC PLLSEL=0x4)
    - REXTPHYS corrected to 3K (was 12K; required for OTGPHYC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
    [USB-pasthrough.kicad_pcb, USB-pasthrough.kicad_sch]
2026-07-24 Fix DFU notes: USART3 (PB10/PB11) is ROM bootloader UART, not USART2
    Per AN2606 Table 97, STM32F723 ROM bootloader supports USART1 and USART3.
    USART2 is not supported on STM32F72xxx/F73xxx. USART1 conflicts with OTG_FS
    pins. Correct path is USART3 on PB10/PB11 (free on v0.2, no header — add in v0.3).
2026-07-26 Sync bringup: ST7735 display driver, SPI fix, display GPIO init
    [main.c, st7735.c, st7735.h]
2026-07-28 Update reflow process based on skillet calibration
    - Remove foil recommendation: foil limits peak to ~190°C (below Sn63Pb37 reflow zone); without foil skillet cycles correctly at 200–220°C
    - Switch to cold-start procedure: dial to 150°C, 2 min soak, then max
    - Hold 30–60 s above liquidus after reflow visible, then kill heat, cool to <100°C on skillet
    - IR reference: scrap PCB with black marker at ε=0.95 (Surpeer GM550)
    - Add tip: paste dab on visible test point gives unobstructed reflow visual cue
    - Document observed skillet thermal cycling behaviour
2026-07-28 Update reflow doc with calibration data and simplified procedure
    - Add actual ramp times: 26°C→150°C in 4 min, →200°C in 7 min, →220°C in 8.5 min
    - Slow ramp (~0.4°C/s) means cold-start-to-max covers preheat/soak naturally; drop two-step dial procedure
    - Remove black tape from equipment list; document why tape/foil/bare skillet fail as IR targets
    - PCB substrate (bare or marker) at ε=0.95 is the only reliable reference surface
    - Simplify cooldown: move to mat once solder solidifies (shiny→matte), not at 100°C
2026-07-29 Add measured TAL data and confirm liquidus+30s kill strategy
    Calibration runs (2026-07-29):
    - Liquidus onset consistent at ~6:21 across multiple runs
    - Neon-out at 220°C mark: TAL ~5 min, peak 222°C — too long for components
    - Neon-out at max: TAL ~9 min, peak 249°C — way over spec
    - Kill at liquidus+30s: TAL ~108s, peak ~200°C — acceptable
    Update calibration table with full ramp data and TAL comparison.
    Add explicit warning: do not use neon out as reflow trigger on populated boards.
    Update process: move to mat at 150°C, tap-test to confirm solidity.
2026-07-29 Commit v0.2 KiCad schematic/PCB and library updates
    - Schematic: xtal frequency updated to 25MHz, REXT to 3KΩ
    - sym-lib-table: fix tps2065c to use relative ${KIPRJMOD} path
    - fp-lib-table: add Library entry
    - Add tps2065c.kicad_sym and SHF-105-01-F-D-TH connector library to kicad/libs/
    Not tagged as sent-to-fab — schematic changes pending v0.2 board order.
    [USB-pasthrough.kicad_pcb, USB-pasthrough.kicad_sch]
2026-07-29 Update cortex Debug connector footprint
    [USB-pasthrough.kicad_sch]
2026-07-31 Display bring-up: ST7735 1.44" working on v0.1 via J5
    Fix pin assignments for v0.1 board (DC=PA8, RST=PA10 vs v0.2 PB1/PA1).
    PA10 repurposed from OTG_FS_ID bodge to LCD_RST; FHMOD still handles host mode.
    Remove PA10 connectivity test (verified good). Update bring-up status.
    [st7735.h]
2026-08-06 Update v0.2 LED current limit resistors for balanced brightness
    Blue: 33Ω (~9mA, Vf~3.0V) — reference, matches v0.1
    Yellow: 100Ω (~12mA, Vf~2.1V) — brighter than v0.1 150Ω
    Green: 390Ω (~3mA, Vf~2.1V) — reduced for eye sensitivity compensation
    All three on TIM1 CH1/2/3 PWM for firmware trim.
    [USB-pasthrough.kicad_sch]
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2026-08-13 Update bring-up status: v0.2 USB-A host working
    AnnePro2 FS HID keyboard fully enumerated on v0.2, key presses
    confirmed 2026-08-12.
    Also records PCB tweak: TP1 footprint drill 1.0mm→0.8mm with
    alignment-library variant.
    [USB-pasthrough.kicad_pcb]
2026-08-14 Sync bringup firmware: full bring-up through USB keyboard passthrough
    Sync ~/STM32F723_bringup into bringup/ — covers all bring-up work since
    initial commit: display, UART2, USB-A host (FS HID keyboard), USB-C device
    (OTG-HS OTGPHYC, 480 Mbps), and USB keyboard passthrough demo.
    Key changes:
    - main.c: LED chase, ST7735 display, USB-A/C init, keyboard passthrough loop
    - syscalls.c: _write() direct USART2 register path for printf
    - usbd_conf.c: OTG-HS OTGPHYC FS/HS init, BVALOEN software session override
    - usbh_conf.c: OTG-FS host, FHMOD, VBUS permanently on
    - usbd_hid: replace mouse descriptor with 8-byte boot keyboard descriptor
    - .gitignore: exclude build/ and Drivers/ (152 MB HAL librar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
    [main.c, st7735.h]
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2026-08-14 3dprint: base plate for v0.2 board — 44x84mm, 4mm standoffs with 2mm pins
    [baseplate.scad]
2026-08-15 CLAUDE.md: correct DFU notes — AN2606 Table 44, USART3 PB10/PB11, v0.3 plan
2026-08-15 3dprint: update baseplate with ST7735 display mount extension
    [baseplate.scad]
2026-08-15 interposer: init all LEDs low at startup to kill RGB red leakage glow
    [main.rs]
2026-08-15 3d printed board holder
    Add display holder.
    Include stl files.
    [baseplate.scad, baseplate.stl, baseplate_display.stl]
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2026-08-16 Add Embassy USB-A host HID keyboard input (Rust)
    embassy-usb-host + embassy-usb-synopsys-otg wired up for OTG_FS host
    mode: custom interrupt handler, NVIC enable, FIFO/channel config.
    KbdHandler reads boot-protocol reports; keycodes print via defmt.
    AnnePro2 SET_PROTOCOL STALL handled non-fatally as before.
    [main.rs]
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2026-08-16 Fix disconnect detection; add yellow flash for NotAKeyboard
    Use select(controller.wait_for_device_event(), kbd.wait_for_event())
    in inner loop so port disconnect event wakes and unblocks the pending
    interrupt IN transfer. Add KeyboardDisconnected signal on disconnect.
    Yellow LED flashes (toggle on 500ms tick) for NotAKeyboard state.
    [main.rs]
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2026-08-19 Initial SPI Display task
    Add ST7735s 128x128 display bring-up via mipidsi 0.10: display_task with
    SpiInterface, BGR color order, embedded-graphics text rendering. Also add
    SDMMC feature flags (sdmmc_1bit/sdmmc_4bit/gpio-test) and STBITERR errata
    fix (check DBCKEND before STBITERR in SDMMCv1 data path).
    [main.rs, mod.rs]
2026-08-19 Fix ST7735s display offset and text rendering
    Add display_offset(2, 1) to correct 132-column controller window alignment
    for 128x128 visible area; fixes red artifact line on right edge. Switch to
    FONT_6X10 for readable text starting at Point(0, 10).
    [main.rs]
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2026-08-19 Add DisplayChannel for inter-task display messaging
    Add DisplayCmd enum (WriteLine, Clear) and static DISPLAY_CHANNEL. display_task
    now loops on channel receive, drawing body text at specified row with FONT_5X7.
    sd_task sends SD card size on successful init; Clear resets display on error.
    [main.rs]
2026-08-20 Add USB MSC skeleton (Bulk-Only Transport + SCSI stub)
    Implement msc.rs with BOT protocol loop: CBW parse, SCSI dispatch (INQUIRY,
    TEST UNIT READY, REQUEST SENSE, MODE SENSE, READ/WRITE CAPACITY stubs), CSW
    response. Wire composite HID+MSC into embassy-usb Builder. Store Msc in
    StaticCell to avoid task future stack overflow. Add wait_enabled() before
    endpoint reads to survive USB init ordering.
    [main.rs]
2026-08-20 Fix MSC bulk endpoint size and EP_OUT_BUF for HS operation
    Change bulk endpoints to 512 bytes (required for HS), increase EP_OUT_BUF
    to 1024 bytes to accommodate 512-byte OUT endpoint. MSC now enumerates
    cleanly as composite HID+MSC with no invalid maxpacket warnings. Endpoint
    enabled confirmed after SET_CONFIGURATION.
    [main.rs]
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2026-08-20 Implement USB MSC READ(10) with real SD card data
    - MscSd struct wraps StorageDevice<Card> with SdAccess trait
    - read_sector converts DataBlock [u32;128] to [u8;512] via to_le_bytes
    - CBW read changed from read_exact to single ep_out.read (fixes host hang)
    - READ_CAPACITY_10 uses sd.capacity_sectors()-1 (real card size)
    - INQUIRY additional length byte (r[4]=31) fixes SCSI spec warning
    - SD card init moved into msc_task; sd_task removed
    [main.rs]
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2026-08-21 Increase SD clock to 12MHz and reduce RTT log noise
    Change SDMMC operating frequency from 400kHz (init speed) to 12MHz
    for data transfers — 400kHz was the primary cause of very slow MSC
    throughput. Remove repeated TEST UNIT READY log messages.
    [main.rs]
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2026-08-22 Add SD card removal/insertion detection and BOT MSC control handler
    - cdet_task polls PE3 every 100ms, updates CARD_PRESENT AtomicBool
    - msc_task waits for card, inits SD, calls run() then run_no_card()
    - run_no_card() services ep_out with NOT READY responses while card
    absent; exits when card reinserted; uses 200ms timeout to recheck
    - SenseState enum (Good/NotReady/UnitAttention) with correct transitions:
    TEST_UNIT_READY checks state; REQUEST_SENSE returns data and clears
    - signal_unit_attention() called on insertion for clean host remount
    - READ_CAPACITY_10, READ_10, WRITE_10 set NotReady sense on failure
    - MscControl implements embassy_usb::Handler to handle BOT class requests:
    0xF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
    [main.rs]
2026-08-22 Fix start-without-card and update bring-up status
    Firmware: msc_task now starts directly in run_no_card() so the SCSI
    layer can complete its initial INQUIRY immediately after enumeration,
    even with no SD card present. run_no_card() handles INQUIRY with a
    full device response and CSW_OK; REQUEST_SENSE returns NOT READY sense
    and CSW_OK; everything else returns CSW_FAIL.
    CLAUDE.md: mark SD card removal/insertion/change detection complete;
    note known issue (no automount when starting without card inserted).
    [main.rs]
2026-08-22 Add PM state machine skeleton and fix display text overwrite
    pm.rs: new module with Mode enum (Passthrough/PmSelect), PmState struct,
    and PmAction return type. Scroll Lock toggles between Passthrough and
    PmSelect; Passthrough forwards HID reports, PmSelect swallows keys.
    State label displayed at row 28 on mode change.
    main.rs: wire in pm module — PmState created in kbd_task before outer
    loop, initial mode sent to display on start, handle_key() called on
    each KeyStatusUpdate with passthrough/swallow/display dispatch.
    Fix display text overwrite: switch body_style to MonoTextStyleBuilder
    with background_color(BLACK) so character cells are cleared before
    rendering, preventing old text bleedi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
    [main.rs]
2026-08-22 PM state machine: full credential flow with HID typing
    - Rewrite pm.rs with complete state machine: PmSelect, PmTypeUser,
    PmTypePass; Scroll Lock toggles passthrough/PM; Up/Down navigates;
    Tab/Enter advances through site label → username → password
    - Up/Down in PmTypeUser backs up to PmSelect (restores site label)
    rather than staying in username mode at adjacent credential
    - PmEffect replaces PmAction: compound struct carrying erase count,
    text to type, optional send_key, and display row updates
    - char_to_hid() maps printable ASCII to HID (keycode, modifier) pairs
    - Reduce HID poll_ms 10 → 1 for faster credential typing
    - Add tools/login_prompt.py: username + masked password pr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
    [baseplate.scad]
